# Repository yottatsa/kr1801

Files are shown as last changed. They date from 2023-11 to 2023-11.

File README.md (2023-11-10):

# KR1801 computer

KiCAD goodies to work with K1801VM1

[Documenation](https://yottatsa.github.io/kr1801/).

## К1801ВМ1 (K1801VM1)

KiCAD symbol and footprint, 3D model.

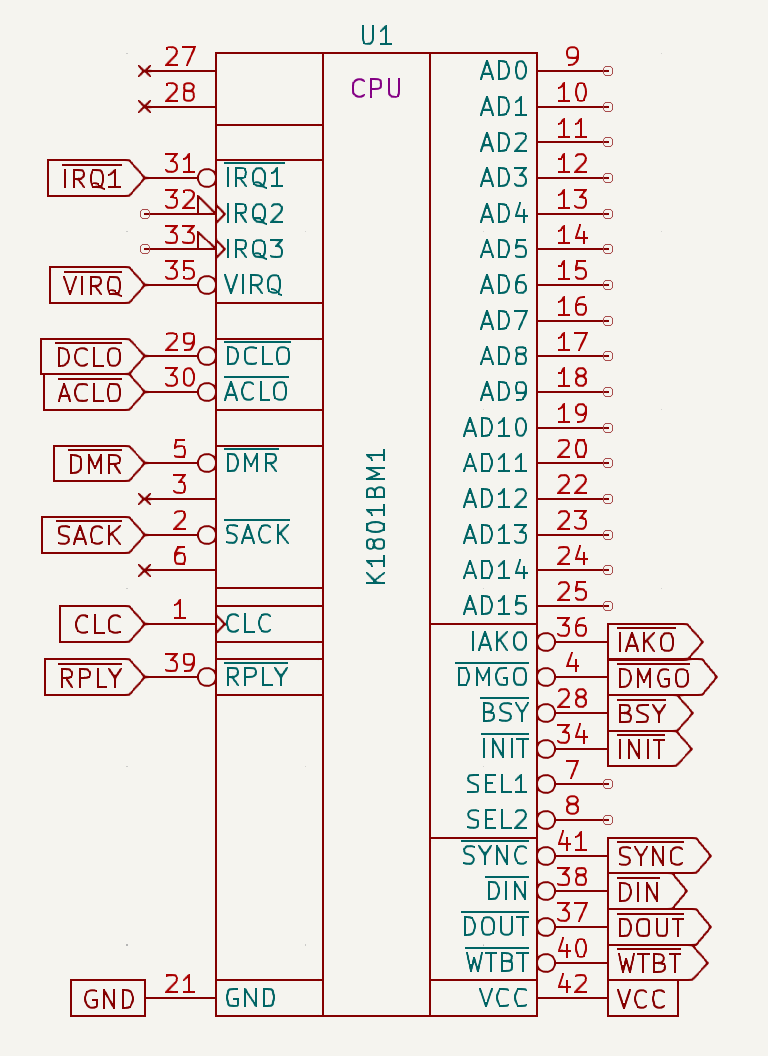
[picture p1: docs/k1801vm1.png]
Screenshot of a K1801VM1 KiCAD symbol


## Retrobrew EuroCard bus v6

KiCAD symbol with most of the pins in 16bit configuration (to be finished).

## KR1801VM1 ECB card

Minimal card that has clock and facilities to boot.

## Documentation sources

* [1801BM1/cpu11](https://github.com/1801BM1/cpu11/tree/6452c7d89c5c2e69dccbcec1f96eda947a3de05e/vm1/doc)
* [arktur04/1801VM1_docs](https://github.com/arktur04/1801VM1_docs)

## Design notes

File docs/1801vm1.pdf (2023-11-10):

# Однокристальный микропроцессор К1801ВМ1 Техническое описание

## Версия 1.2 (October 24, 2020)

Однокристальный микропроцессор К1801ВМ1 | Version: 1.2
Техническое описание © 1801BM1@gmail.com | Date: 24-Oct-2020

### 1. Введение

Данный документ описывает микросхему советского однокристального микропроцессора К1801ВМ1. В открытом доступе не имеется официального технического описания данного процессора, а различные источники не являются полными и непротиворечивыми, поэтому было принято решение составить техническое описание, основанное на имеющихся фрагментах официальных документов, проверенных на практике фактов и результатах реверс-инжиниринга собственно микросхемы К1801ВМ1.

По возможности ссылки на использованные материалы приведены в соответствующем разделе.

В тексте не делается различия между разными исполнениями корпуса - КМ1801ВМ1 (керамический), КР1801ВМ1 (пластиковый корпус) и прочими, вместо этого употребляется единое обозначение К1801ВМ1.

Изначально, когда выполнялся реверс-инжиниринг микросхемы К1801ВМ1А, предполагалось что микросхемы с другими буквенными индексами (К1801ВМ1Б, К1801ВМ1В, К1801ВМ1Г) являются результатом сортировки по частоте и работоспособности отдельных блоков после выполнения заводских тестов. Данное предположение оказалось только частично верным. Микросхема К1801ВМ1Г выпускалась по другим фотошаблонам слоя диффузии и содержит микропрограмму, отличную от микропрограммы микросхемы К1801ВМ1А. Функциональные отличия микросхемы К1801ВМ1Г заключаются в поддержке команды умножения, гарантировано работоспособном блоке таймера и поддержке прерывания от этого блока. Поскольку данные отличия незначительны, то возможно написание единой документации на все варианты К1801ВМ1, с акцентированным описанием дополнительных особенностей версии К1801ВМ1Г.

### 2. Назначение

Микросхема К1801ВМ1 является однокристальным 16-ти разрядным микропроцессором (далее по тексту процессор), предназначенным для обработки цифровой информации.

В составе ЭВМ процессор может использоваться для управления технологическими процессами, в контрольно-измерительной аппаратуре, в системах связи, для решения инженерно-технических и экономических задач.

### 3. Технические характеристики

Представление чисел | дополнительный код с фиксированной запятой
Система команд | безадресная, одноадресная, двухадресная
Виды адресации | регистровая, косвенно-регистровая, автоинкрементная, косвенно-автоинкрементная, автодекрементная, косвенно-автодекрементная, индексная, косвенно-индексная
Число регистров общего назначения | 8
Число уровней прерываний | 4
Системная магистраль | типа МПИ
Адресное пространство | 64 килобайта
Тактовая частота К1801ВМ1А К1801ВМ1Б К1801ВМ1В К1801ВМ1Г | минимальная 100 кГц для всех вариантов (ограничение частоты снизу связано с тем, что для построения некоторых защелок используется емкость затворов n-МОП транзисторов) до 4.7 МГц (ВМ1А) до 3.5 МГц (ВМ1Б) до 2.5 МГц (ВМ1В) до 4.7 МГц (ВМ1Г)
Максимальное быстродействие (регистровые операции) | до 500 тысяч операций в секунду
Напряжение питания | однополярное единое питание +5 В ±10%
Многопроцессорность | до 4-х процессоров на единой магистрали
Уровни входных логических сигналов низкого уровня высокого уровня | не более 0.6 В, при токе не утечки не более 50мкА не менее 2.4 В, при токе не утечки не более 50мкА
Уровни выходных логических сигналов низкого уровня высокого уровня | не более 0.5 В, при втекающем токе 3.2мА не менее 2.4 В, при вытекающем токе -0.2 мА
Емкость нагрузки | до 100 пФ
Технология изготовления | n-МОП, типовая ширина затвора транзистора ~3 мкм, один слой металла и один слой поликремния
Размер кристалла | 5х5 мм
Конструкция | Металлокерамический корпус типа 429.42 или пластиковый 2204.42-3
Количество транзисторов | ~16650 штук
Потребляемая мощность | до 1.2 Вт

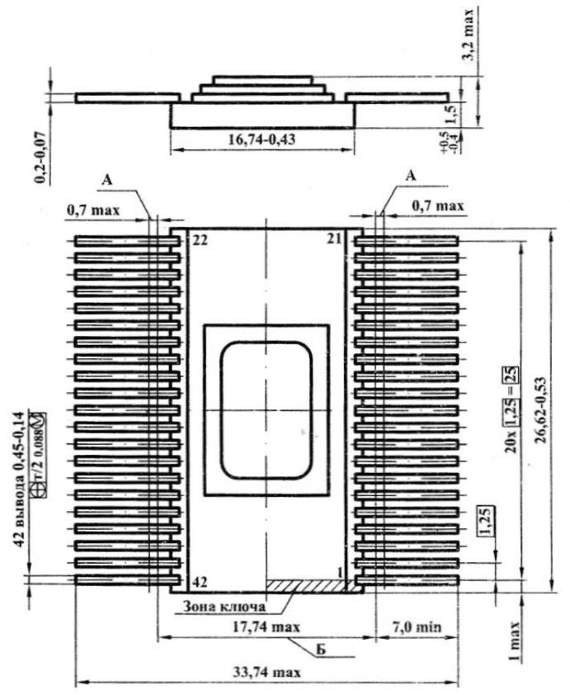
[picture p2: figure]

Чертеж планарного металлокерамического корпуса типа 429.42-5

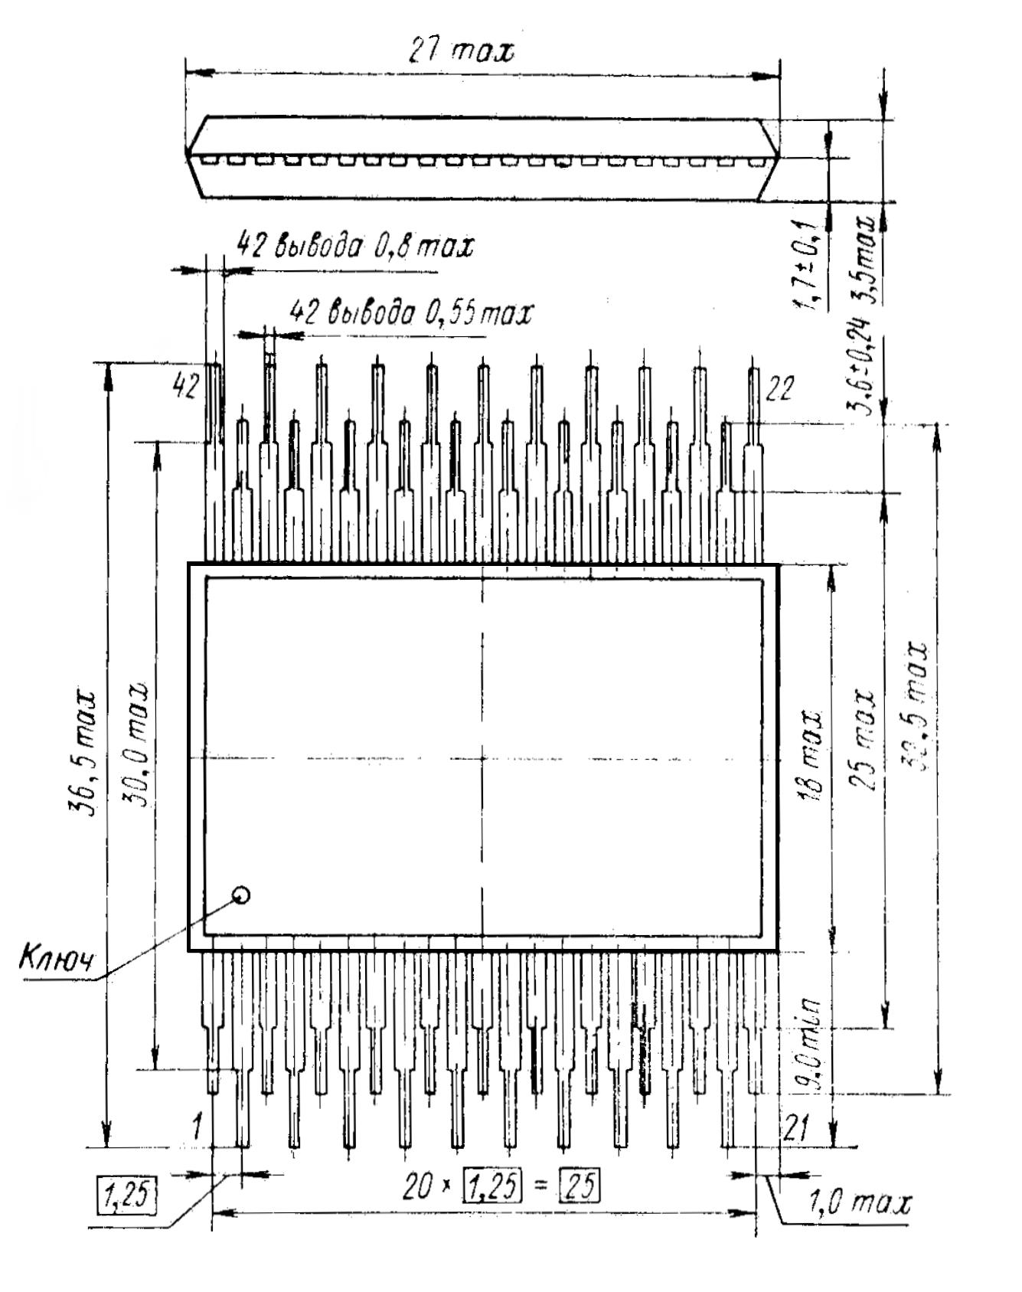
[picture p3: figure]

Чертеж планарного пластикового корпуса 2204.42-3

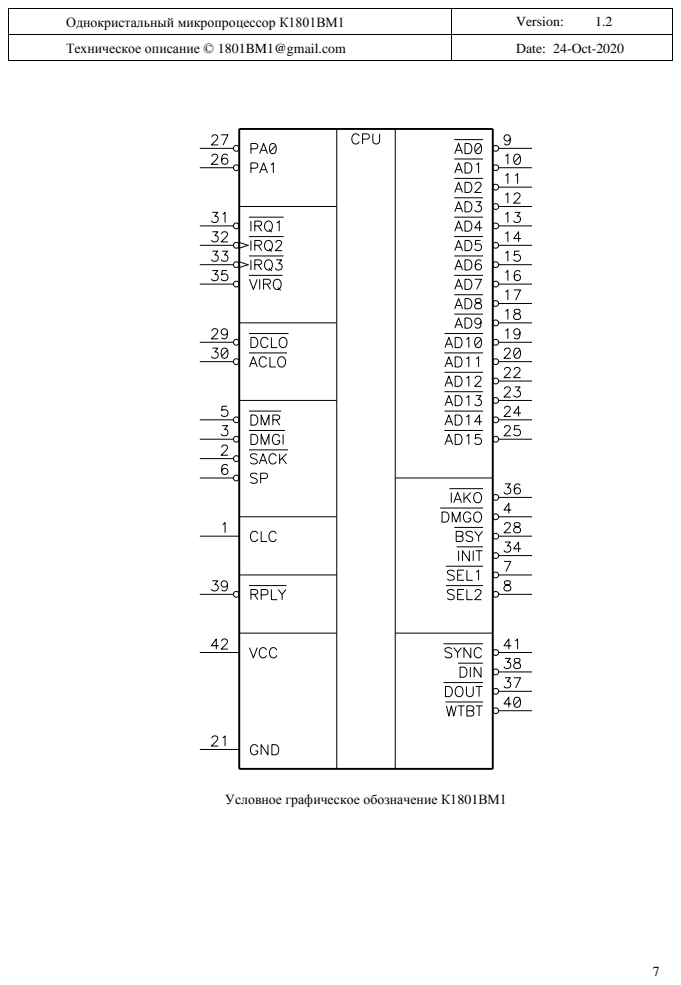
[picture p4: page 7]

Условное графическое обозначение К1801ВМ1

### 4. Назначение выводов

1 | CLC | вход | Основной тактовый сигнал частотой не менее 100 кГц, ограничение частоты снизу связано с широким применением динамической логики в схеме процессора. Под динамической логикой понимается использование емкостных свойств затворов n-МОП транзисторов, вследствие чего транзисторы могут некоторое время сохранять свое состояние при затворе, отключенном от источника сигнала
2 | nSACK | вход выход-ОК | Подтверждение захвата магистрали внешним агентом Ведущий процессор с аппаратным номером 0 никогда не активизирует данный выход (типа открытый коллектор). Ведомые процессоры с номерами 1-3 выставляют на данном выходе низкий уровень в процессе обмена по магистрали. Как вход используется всеми процессорами для общего контроля занятости магистрали
3 | nDMGI | вход | Разрешение от внешнего арбитража на доступ к магистрали, если процессор в данный момент занят выполнением внутренних операций и ему не требуется доступ к магистрали, то обеспечивается дальнейшее прохождение разрешающего сигнала на выход nDMGO
4 | nDMGO | выход | Разрешение на доступ к магистрали другим, менее приоритетным модулям. Активный низкий уровень появляется в моменты, когда на входе nDMGI низкий уровень и внутреннему процессорному блоку не требуется доступ к магистрали
5 | nDMR | вход выход-ОК | Для ведущего процессора с аппаратным номером 0 этот вывод является входом запроса на доступ к магистрали от ведомых процессоров с номерами 1-3 и других внешних модулей системы, ведущий процессор никогда не использует данный вывод как выход. Ведомые процессоры с номерами 1-3 используют данный вывод как выход запроса на доступ к магистрали
6 | nSP | вход | Вход периферийного таймера, может использоваться как внешняя тактовая частота, не превышающая одной восьмой тактовой частоты процессора, или как вход защелкивания текущего значения счетчика таймера в отдельном регистре. Все действия в таймере (счет и защелкивание) происходят по ниспадающему фронту сигнала на данном входе с задержкой от 1 до 8 тактов процессорной частоты CLC
7 | nSEL1 | выход-ОК | Сигнал подтверждения обращения по адресу база внутреннего периферийного блока + 168. Формируется всегда, независимо от того какой агент, внутренний или внешний обращается к данному адресу.
8 | nSEL2 | выход-ОК | Сигнал подтверждения обращения по адресу база внутреннего периферийного блока + 148. Формируется всегда, независимо от того какой агент, внутренний или внешний обращается к данному адресу.

9-20,
22-25

nAD0-
nAD15

входы
выходы-3

Линии 16-ти разрядной мультиплексированной шины адреса и данных. Сигналы передаются по данным линиям в инвертированном виде. Передача значения адреса и данных осуществляется методом разделения во времени.

Если системной магистралью МПИ владеет внутренний процессорный блок, то выводы nAD работают как выходы:

- в фазе передачи адреса
- в фазе записи данных во всем диапазоне адресов
- в фазе чтения данных из диапазона адресов внутреннего периферийного блока , за исключением двух старших адресов nSEL1 и nSEL2.
Если системной магистралью МПИ владеет внешний по отношению к микросхеме агент , то выводы nAD работают как выходы:
- в фазе чтения данных по адресам внутреннего периферийного блока

В остальное время выходы находятся в высокоимпедансном состоянии. Входы в целях мониторинга адреса транзакции и данных записи работают постоянно.

26, 27 | nPA1, nPA0 | входы | Аппаратный номер процессора в многопроцессорной системе, сигналы на данных входах являются инвертированными. nPA1=1, nPA0=1 - процессор номер 0, высший приоритет nPA1=1, nPA0=0 - процессор номер 1 nPA1=0, nPA0=1 - процессор номер 2 nPA1=0, nPA0=0 - процессор номер 3, низший приоритет Если процессор единственный в системе (однопроцессорный вариант), то на данные входы должен быть подан высокий уровень. От аппаратного номера процессора зависит базовый адрес блока регистров внутреннего периферийного блока.
28 | nBSY | выход-ОК | Низкий уровень на данной выходе сигнализирует о выполнении транзакции на шине МПИ
29 | nDCLO | вход | Авария источника питания постоянного напряжения. Низкий уровень на данном входе выставляется внешней схемой при выходе питающего напряжения системы (обычно +5V и +12V) за допустимые рабочие диапазоны, при этом происходит безусловный аппаратный сброс процессора.
30 | nACLO | вход | Авария сетевого источника питания. Низкий уровень на данном входе выставляется внешней схемой при выходе сетевого питающего напряжения за пределы рабочего диапазона, при этом внутренние постоянные питающие напряжения все еще могут обеспечиваться. Ниспадающий фронт вызывает прерывание по вектору 0248, для устойчивой работы процессора сигнал следует синхронизировать по нарастающему фронту с тактовой частоты CLC. По нарастающему фронту сигнала происходит старт микропрограммного автомата, если он был сброшен ранее активным сигналом nDCLO

31 | nIRQ1 | вход | Первый запрос на радиальное прерывание, низкий уровень вызывает прерывание по вектору 1600028. Для устойчивой работы процессора сигнал следует синхронизировать по нарастающему фронту с тактовой частоты CLC
32 | nIRQ2 | вход | Второй запрос на радиальное прерывание, ниспадающий фронт вызывает прерывание по вектору 1008, для устойчивой работы процессора сигнал следует синхронизировать по нарастающему фронту с тактовой частоты CLC
33 | nIRQ3 | вход | Третий запрос на радиальное прерывание, ниспадающий фронт вызывает прерывание по вектору 2708, для устойчивой работы процессора сигнал следует синхронизировать по нарастающему фронту с тактовой частоты CLC
34 | nINIT | вход выход-ОК | Вход сброса периферийных устройств. Низкий уровень на данном входе переводит периферийный таймер в исходное состояние и временно снимается активный запрос nDMR. Также приводятся в исходное состояние детекторы ниспадающего фронта на входах nIRQ2 и nIRQ3. На выходе (открытый коллектор) формируется активный сигнал низкого уровня при выполнении инструкции RESET и/или аппаратном сбросе процессора
35 | nVIRQ | вход | Запрос на векторное прерывание, низкий уровень вызывает цикл подтверждения прерывания на шине МПИ и переход по прочитанному из внешнего устройства вектору. Для устойчивой работы процессора сигнал следует синхронизировать по нарастающему фронту тактовой частоты CLC. Следует отметить, что только ведущий процессор с аппаратным номером 0 может принимать и обрабатывать прерывания по данному входу, в ведомых процессор с аппаратными номерами 1-3 этот вход заблокирован.
36 | nIAKO | выход-3 | Выход предоставления прерывания, низкий уровень на данном выходе появляется в циклах чтения вектора прерывания из внешнего устройства. Когда доступ к шине МПИ процессору не предоставлен выход находится в высокоимпедансном состоянии
37 | nDOUT | вход выход-3 | Вывод данных, вход используется внутренним периферийным блоком для выполнения транзакций записи. Выходом управляет процессорный блок в случае предоставления ему доступа к шине МПИ. Когда доступ к шине процессору не предоставлен выход находится в высокоимпедансном состоянии
38 | nDIN | вход выход-3 | Ввод данных, вход используется внутренним периферийным блоком для выполнения транзакций чтения. Выходом управляет процессорный блок в случае предоставления ему доступа к шине МПИ, когда доступ к шине процессору не предоставлен выход находится в высокоимпедансном состоянии
39 | nRPLY | вход выход-ОК | Подтверждение обмена данными, вход используется процессорным блоком при выполнении транзакций на шине МПИ. На выходе генерируется активный низкий уровень периферийным блоком в случае любого обращения в его диапазон адресов, включая регистры nSEL1 и nSEL2. Из-за выявленных ошибок в схеме процессора

| | | сигнал на данном входе следует синхронизировать с тактовым сигналом CLC (с любым из фронтов) для обеспечения устойчивой работы
40 | nWTBT | выход-3 | Запись/байт, в фазе трансляции адреса данный выход индицирует низким уровнем что в данной транзакции будет осуществляться вывод данных. Для циклов чтение и чтение-модификация-запись на данном выходе присутствует высокий уровень. В фазе обмена данными низкий уровень свидетельствует о записи одного из байтов, а не целого слова. Какой именно байт записывается определяется состоянием младшей адресной линии в фазе передачи адреса. Когда доступ к шине процессору не предоставлен выход находится в высокоимпедансном состоянии
41 | nSYNC | вход выход-3 | Вход используется периферийным блоком для мониторинга адреса транзакции. Выходом управляет процессорный блок при выполнении транзакций на шине МПИ. При этом выход имеет особенность -высокий уровень генерируется ровно на один такт частоты CLC, после чего выход переводится в высокоимпедансное состояние, поэтому для нормальной работы линия должна быть подтянута резистором к напряжению питания.
21 | GND | земля | опорный уровень 0В, питание
42 | VCC | питание | +5В с допуском ±10%, ток потребления до 240мА

Микросхема К1801ВМ1 содержит внутри два основных блока - собственно блок процессора и периферийный блок. Оба блока подключены к единой магистрали типа МПИ, которая также выходит на внешние выводы. Блок процессора может работать только как ведущий агент МПИ, периферийный блок может работать только как ведомый агент МПИ. Доступ процессорного блока к управлению МПИ контролируется модулем арбитража. Периферийный блок представляет собой набор различных специальных регистров, для периферийного блока выделен адресный диапазон из 8 16-ти разрядных слов, базовый адрес которого определяется аппаратным номером процессора. Внешние выводы МПИ микросхемы К1801ВМ1 выполняют совмещенные функции для процессорного и периферийного блоков. Доступ к периферийному блоку может осуществляться как со стороны внутреннего процессорного блока, так и со стороны внешнего по отношению к микросхеме процессора агента шины МПИ. Таким образом, можно выделить основные четыре режима работы внешних выводов МПИ микросхемы К1801ВМ1:

- доступ внутреннего процессорного блока к внешним адресам системы (которые, в том числе, могут быть адресами периферийного блока другой микросхемы К1801ВМ1 в многопроцессорной системе)
- доступ внутреннего процессорного блока к адресам внутреннего периферийного блока
- доступ внешнего агента к внешним адресам системы
- доступ внешнего агента к адресам внутреннего периферийного блока данного процессора

Особый случай представляют два старших адреса периферийного блока, эти регистры могут реализовываться на внешних схемах, но при этом управление обменом по МПИ осуществляется процессором, внешние схемы только представляют или получают данные, сигнал nRPLY формируется выходом К1801ВМ1 всегда, при обращении к любому адресу из диапазона периферийного блока.

Процессор К1801ВМ1 может работать в составе многопроцессорной системы с разделением общей магистрали МПИ. Система на основе К1801ВМ1 может содержать до 4-х процессоров. Процессорам присваивается аппаратный номер от 0 до 3, в зависимости от уровней, поданных на входы nPA0-nPA1. Процессор с аппаратным номером 0 называется ведущим и имеет высший приоритет при доступе к разделяемой шине МПИ, начиная цепочку арбитража по выводам nDMGI/nDMGO. Остальные процессоры с номерами 1-3 называются ведомыми, приоритет доступа к разделяемой шине определяется местом включения процессора в цепочку арбитража доступа к шине

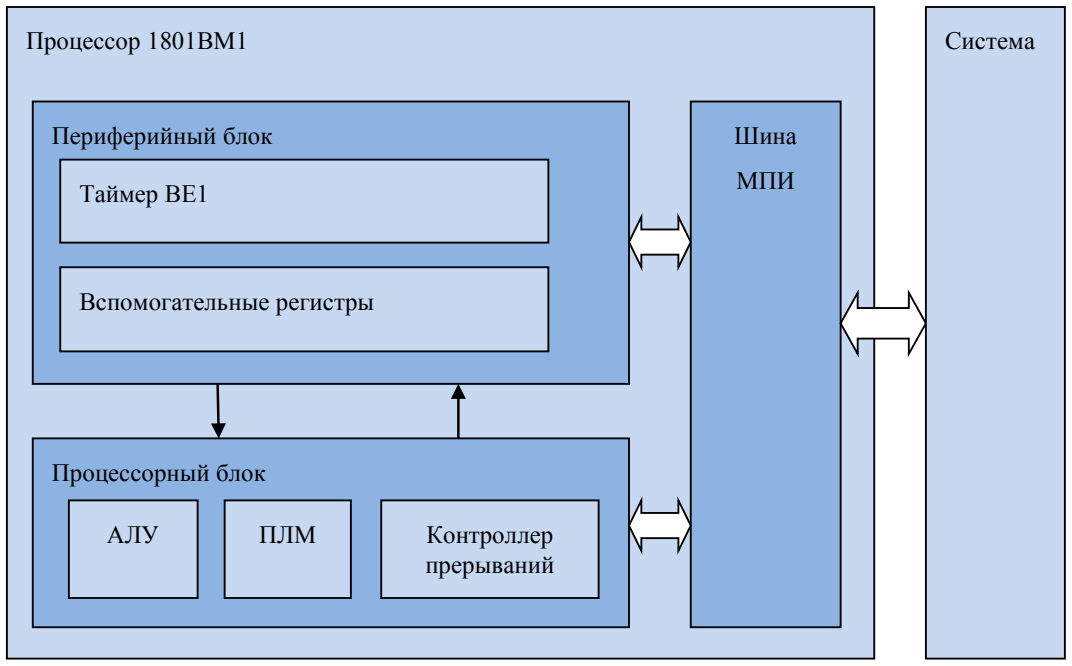
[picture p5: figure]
Процессор 1801ВМ1; Периферийный блок; Процессорный блок; Шина; МПИ Таймер ВЕ1; Вспомогательные регистры; АЛУ; ПЛМ; Контроллер; прерываний; Система

### 5. Шина МПИ

Микропроцессор К1801ВМ1 для обмена с внешними устройствами использует системную шину типа МПИ (Магистральный Параллельный Интерфейс). Обмен информацией между двумя устройствами по шине МПИ осуществляется по принципу ведомый-ведущий. Управление обменом осуществляет ведущее устройство, а ведомое устройство производит подтверждение приема или передачи слова данных. Некоторые устройства могут в разные моменты времени выполнять роль как ведущего, так и ведомого. В каждый момент времени на шине МПИ может быть только одно ведущее устройство, которое физически осуществляет управление линиями магистрали. Доступ устройства к роли ведущего шины разрешается средствами приоритетного арбитража. Подробно с регламентом работы МПИ можно ознакомиться в стандарте "ГОСТ 26765.51-86 Интерфейс магистральный параллельный МПИ системы электронных модулей. Общие требования к совокупности правил обмена информацией" [6]. Данная же документация делает акцент именно на особенностях работы микропроцессора, для понимания принципов работы внешних устройств следует обратиться к упомянутому ГОСТ.

Микропроцессор К1801ВМ1 может выполнять роль ведущего устройства шины - в этом случае процессорный блок выполняет транзакции "Ввод" (чтение данных из внешнего устройства), "Вывод" (запись данных во внешнее устройство), "Ввод-Вывод" (чтение-модификация-запись), "Подтверждение прерывания" (чтение вектора прерывания). Так же микросхема К1801ВМ1 может выполнять роль ведомого устройства - в этом случае осуществляется доступ внешним агентом к периферийному блоку микросхемы, а также выполнять обе роли ведущего и ведомого устройств одновременно - при обращении процессорного блока к собственному (то есть, находящемуся в той же микросхеме) периферийному блоку. Блочные транзакции шины МПИ микропроцессор К1801ВМ1 не использует.

### 5.1 Транзакция "Чтение"

Ниже приведена диаграмма выполнения микропроцессором цикла чтения данных по шине МПИ в качестве ведущего устройства. Пунктирными линиями показано состояние высокого импеданса. Обычно в системе на линиях магистрали имеются подтягивающие резисторы, поэтому можно полагать что в эти моменты времени на линиях присутствует напряжение высокого уровня, все управляющие сигналы при этом принимают неактивное значение, на шине адрес/данных устанавливается логическое нулевое значения, поскольку шина инвертирована (напряжение низкого уровня соответствует логическому "1", напряжение высокого уровня соответствует логическому "0").

Также указана привязка установки и снятия управляющих выходов к фронтам тактового сигнала, при этом не учитывается внутренняя задержка буферных цепей, которая может достигать десятков наносекунд и, при высоком значении тактовой частоты, может быть сравнимой с длительностью такта.

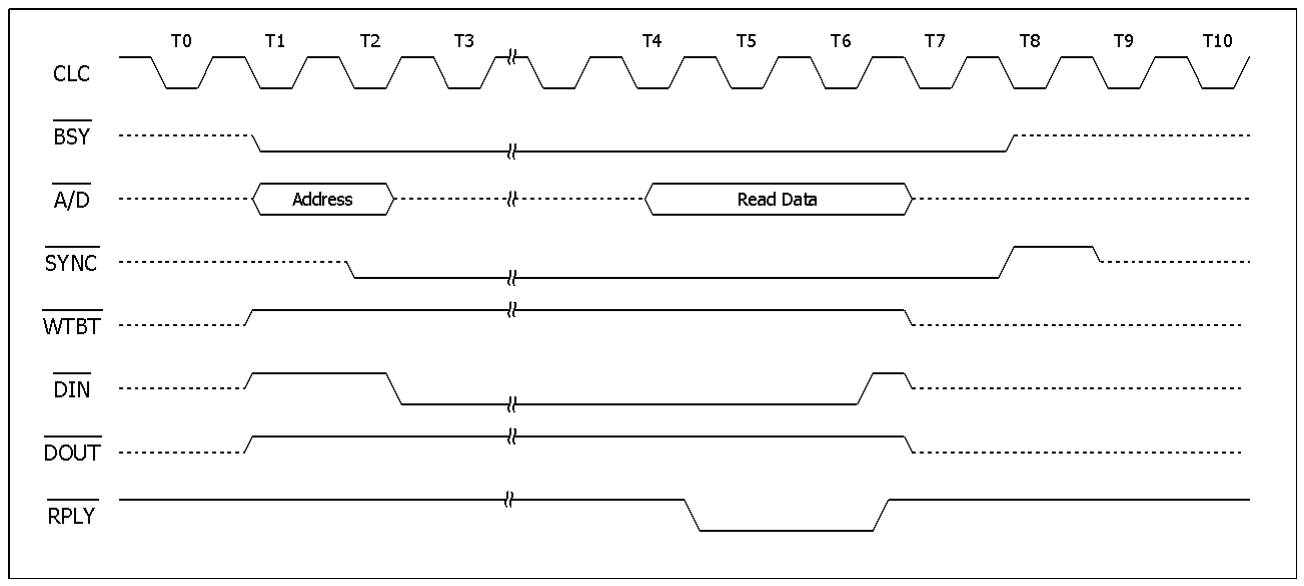
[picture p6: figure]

В такте Т0 на магистрали МПИ нет ведущего устройства, обмен не выполняется, полагаем это состояние исходным. По срезу Т1 микропроцессор осуществляет захват магистрали (процесс арбитража рассмотрен подробно в соответствующем разделе), при этом разрешается управление выходами nWTBT, nDIN, nDOUT, nIAKO, A/D. Сигнал nBSY принимает активный низкий уровень, на шине адреса/данных устанавливается адрес читаемых данных. Выход сигнала nSYNC остается запрещенным — это особенность К1801ВМ1, для корректной работы шины в этом случае требуется внешний подтягивающий резистор. На выходе nWTBT установлен высокий уровень, что означает выполнение операции чтения. По срезу Т2 на выходе nSYNC формируется активный низкий уровень. По фронту Т2 выставленный адрес снимается с шины и выводы nAD переводятся в высокоимпедансное состояние, также выставляется активный низкий уровень на линии nDIN, далее микропроцессор переходит в состояние ожидания данных и сигнала подтверждения nRPLY от ведомого устройства. При этом запускается специальный таймер монитора шины, который осуществляет счет с частотой CLC/8. Если сигнал подтверждения nRPLY не будет получен в течение 56...64 тактов CLC, то цикл обмена прерывается и возникает программное исключение по вектору 0000048 (или 1600028 - зависит от состояния битов PSW10 и PSW11). Разброс в величине таймаута связан с тем, что фаза предделителя частоты CLC/8 при запуске таймера не обнуляется - предделитель считает непрерывно.

На диаграмме в такте Т4 внешнее устройство выставляет данные, которые подлежат считыванию микропроцессором, и затем, по прошествии некоторого интервала формирует активный низкий уровень сигнала подтверждения nRPLY. В общем же случае, согласно ГОСТ 26765.51-86, актуальные данные должны быть выставлены ведомым устройством не позднее чем 200 нс после среза активации сигнала nRPLY. На диаграмме момент выставления nRPLY, который определяется внешним устройством, намерено показан после фронта T4. Микропроцессор фиксирует сигнал на своем входе nRPLY по нарастающему фронту тактового сигнала, при обнаружении активного низкого nRPLY два фронта тактового сигнала подряд (на приведенной диаграмме это T5 и T6, два цикла нужны так как данные от ведомого устройства могут запаздывать на интервал до 200 нс относительно активации nRPLY), цикл обмена полагается законченным, по фронту T6 фиксируются читаемые данные на входах nAD и передаются внутренним схемам процессора, снимается активный сигнал nDIN и останавливается таймер монитора шины, затем происходит переход в ожидание снятия активного сигнала nRPLY. При этом детектирование неактивного высокого уровня nRPLY осуществляется по последовательным фронту и срезу тактового сигнала - сигнал на входе nRPLY должен быть неактивен сначала при нарастающем фронте CLK, а потом на срезе CLK следующего такта - таково условие срабатывания детектора. При обнаружении неактивного высокого уровня nRPLY запрещаются выходы управляющих сигналов nDIN, nDOUT, nWTBT. Далее, еще через один такт происходит снятие сигнала nBSY и выставление высокого уровня сигнала nSYNC. На диаграмме фронт сигнала nRPLY обнаруживается по срезу Т7, а снятие сигналов nSYNC и nBSY происходит по срезу Т8. Высокий неактивный уровень nSYNC удерживается в течение одного такта и по срезу Т9 выход переходит в высокоимпедансное состояние, микропроцессор перестает выполнять роль ведущего устройства, магистраль полагается незанятой. Следует отметить, что таймер монитора шины в состоянии ожидания деактивации nRPLY не работает, поэтому имеется теоретическая возможность зависания системы.

Микропроцессор К1801ВМ1 чтение данных всегда выполняет 16-битными словами. Если требуется прочитать только один из байтов, то ненужные разряды игнорируются. Также микропроцессор выставляет адрес "как есть" (например чтение по @R0 выставляет на шину адреса непосредственно значение из регистра R0, @#000001 - на шину будет выставлено значение 1 и так далее), и чтение слов по нечетному адресу может приводить к некорректно прочитанным данным, поскольку внешняя память и устройства обычно не поддерживают такой режим - в этом случае для корректного чтения внешним схемам необходимо прочитать из памяти два последовательных слова и собрать из них ожидаемую процессором комбинацию байтов. При чтении байта по четному адресу процессор ожидает данные на линиях nAD0-nAD7, при чтении байта по нечетному адресу данные ожидаются на линиях nAD8-nAD15.

Ниже в справочных целях приведена диаграмма выполнения транзакции "Чтение" из ГОСТ 26765.51-86 с указанием регламентируемых временных параметров.

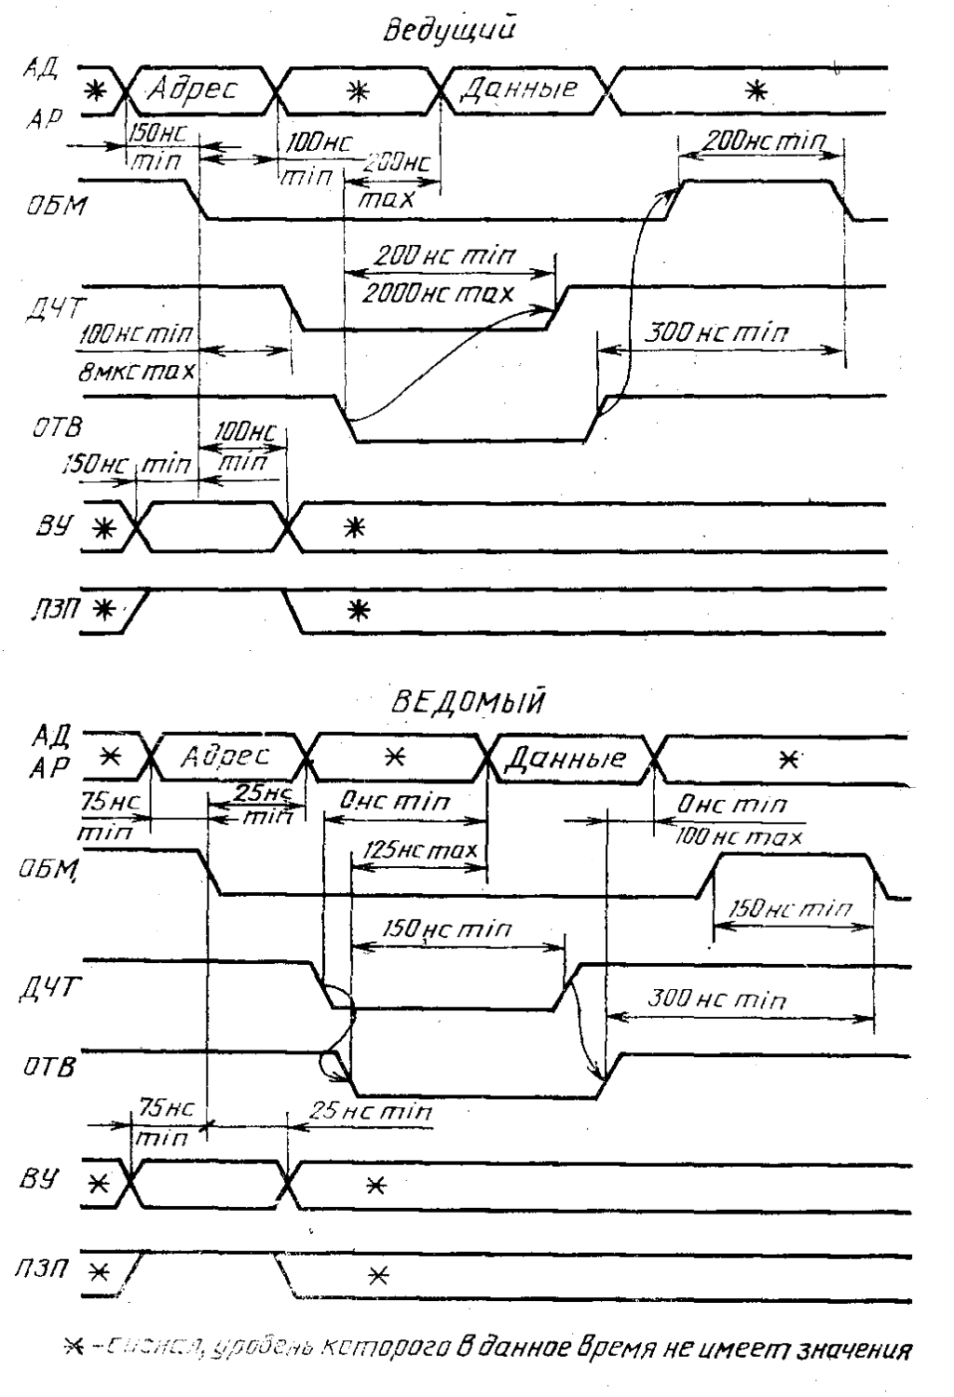
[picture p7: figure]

### 5.2 Транзакция "Запись"

Ниже приведена диаграмма выполнения микропроцессором цикла записи данных по шине МПИ в качестве ведущего устройства.

Начало транзакции аналогично началу транзакции "Чтение". В такте Т0 на магистраль МПИ находится в исходном незанятом состоянии, по срезу Т1 микропроцессор осуществляет захват магистрали, при этом разрешается управление выходами nWTBT, nDIN, nDOUT, nIAKO, A/D. Сигнал nBSY принимает активный низкий уровень, на шине адреса/данных устанавливается адрес записываемых данных. Выход сигнала nSYNC остается запрещенным (особенность К1801ВМ1). На выходе nWTBT установлен низкий уровень, что означает выполнение операции записи. По срезу Т2 на выходе nSYNC формируется активный низкий уровень. По фронту Т2 выставленный адрес снимается с шины, выходы nAD остаются разрешенными и на них транслируется содержимое внутреннего регистра данных микропроцессора. В данный момент там необязательно могут находиться актуальные записываемые в текущей транзакции данные - они могут быть еще не подготовлены внутренними схемами процессора. Время подготовки зависит от того какая программная инструкция в данный момент обрабатывается микропрограммой и может составлять от нуля до нескольких тактов. При готовности данных во внутреннем регистре они начинают транслироваться на внешние выходы по фронту тактового сигнала. Для краткости диаграммы полагаем, что данные выданы внутренними схемами в такте T3, практически же подготовка данных может занимать от нуля до нескольких тактов. По срезу следующего сигнала T4 выставляется активный низкий уровень на линии nDOUT и значение признака байтовой операции nWTBT. Если происходить запись только одного из байтов, то данный признак принимает значение активного низкого уровня. Запись, какого именно байта следует выполнить, определяется значением младшего бита адреса операции. Если происходит запись слова, то признак nWTBT принимает неактивное значение высокого уровня, выполнение операции записи слова по нечетному адресу приводит к некорректной записи данных. Далее микропроцессор переходит в состояние ожидания данных и сигнала подтверждения nRPLY от ведомого устройства. При этом запускается специальный таймер монитора шины, который осуществляет счет с частотой CLC/8. Если сигнал подтверждения nRPLY не будет получен в течение 56...64 тактов CLC, то цикл записи прерывается и возникает программное исключение по вектору 0000048 (или 1600028).

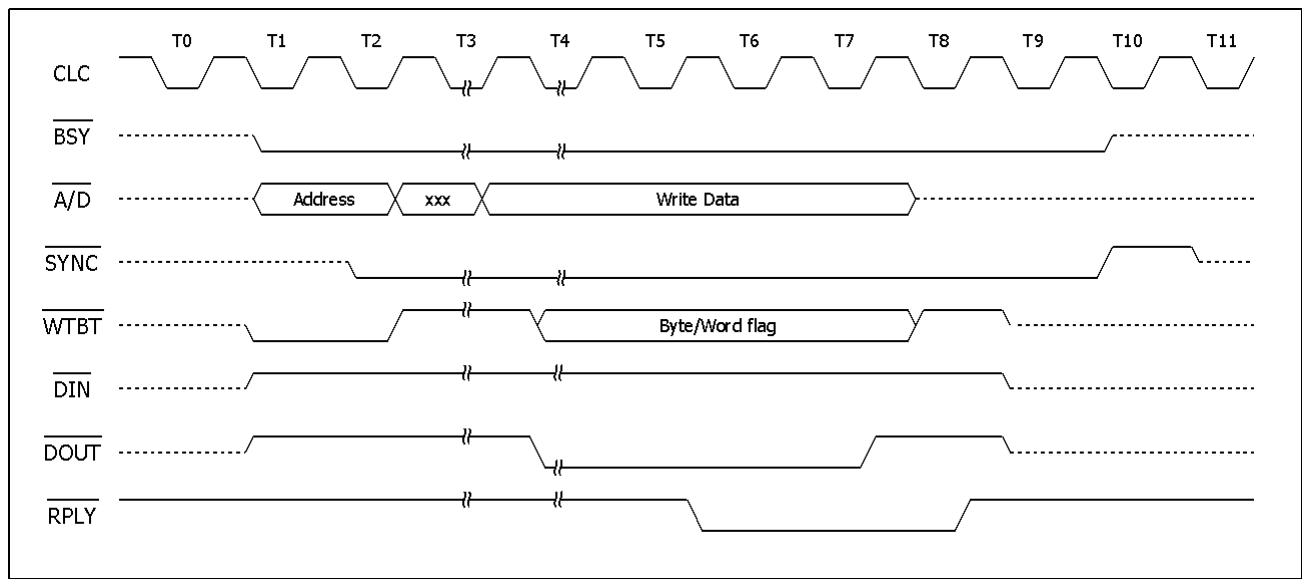
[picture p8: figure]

В такте Т5 внешнее устройство выполняет свою внутреннюю фиксацию записываемых данных с шины и затем, по прошествии некоторого интервала формирует активный низкий уровень сигнала подтверждения nRPLY. На диаграмме момент выставления nRPLY, который определяется внешним устройством, намерено показан после фронта T5. Микропроцессор фиксирует сигнал на своем входе nRPLY по фронту тактового сигнала, при обнаружении активного низкого nRPLY два фронта тактового сигнала подряд (на приведенной диаграмме это T6 и T7), цикл обмена полагается законченным. По фронту T7 деактивируется сигнал nDOUT и останавливается таймер монитора шины, по срезу T8 выходы шины данных A/D запрещаются, шина переходит в высокоимпедансное состояние. Завершение транзакции аналогично завершению транзакции "Чтение" - происходит переход в ожидание снятия активного сигнала nRPLY, при обнаружении деактивируются nSYNC и nBSY, магистраль переходит в неактивное состояние.

Ниже в справочных целях приведена диаграмма выполнения транзакции "Запись" из ГОСТ 26765.51-86 с указанием регламентируемых временных параметров

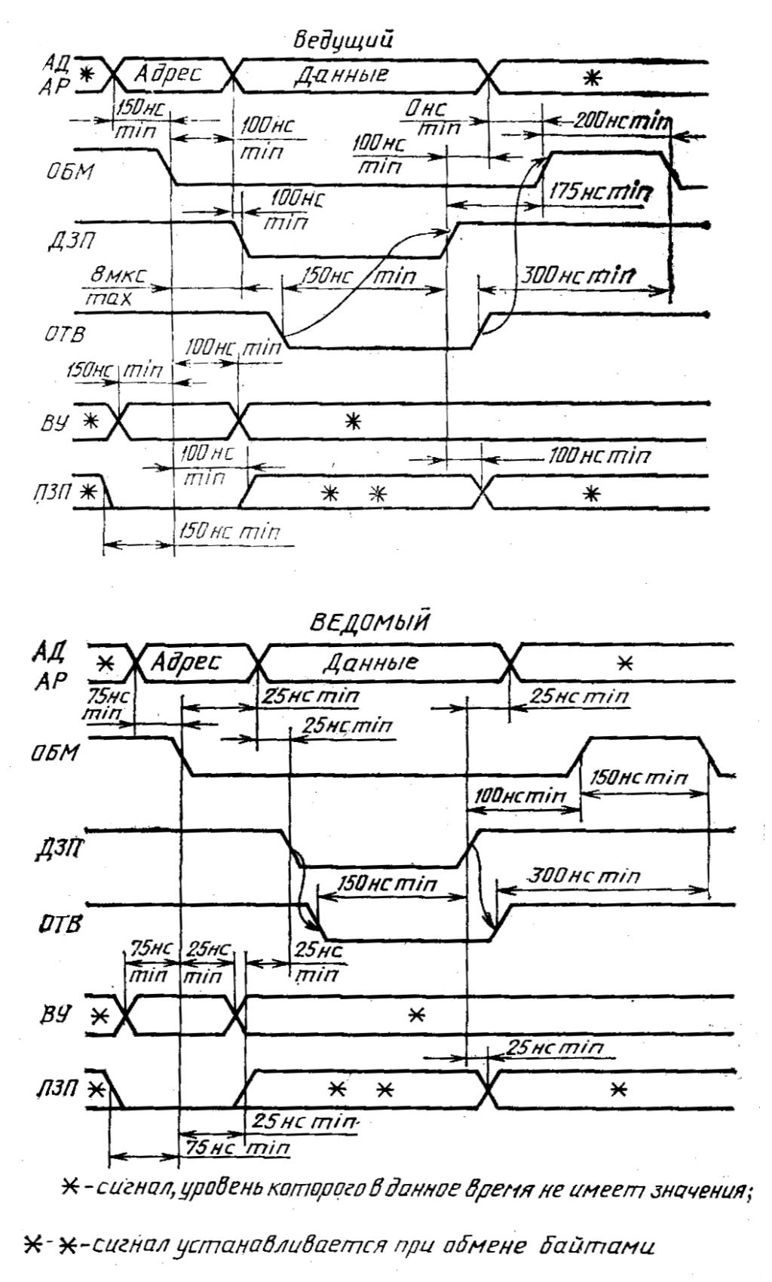
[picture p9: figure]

### 5.3 Транзакция "Чтение-Модификация-Запись"

Транзакция | "Чтение-Модификация-Запись" | имеет | принципиальное | значение | для
многопроцессорных систем, так как позволяет выполнять изменения переменных в памяти атомарно - за одну неразделяемую на части операцию. В этом ее принципиальное отличие от пары, состоящей из отдельной транзакции "Чтение" и последующей транзакцией "Запись" по тому же самому адресу. Ниже приведена диаграмма выполнения микропроцессором цикла чтение-модификация-запись по шине МПИ в качестве ведущего устройства.

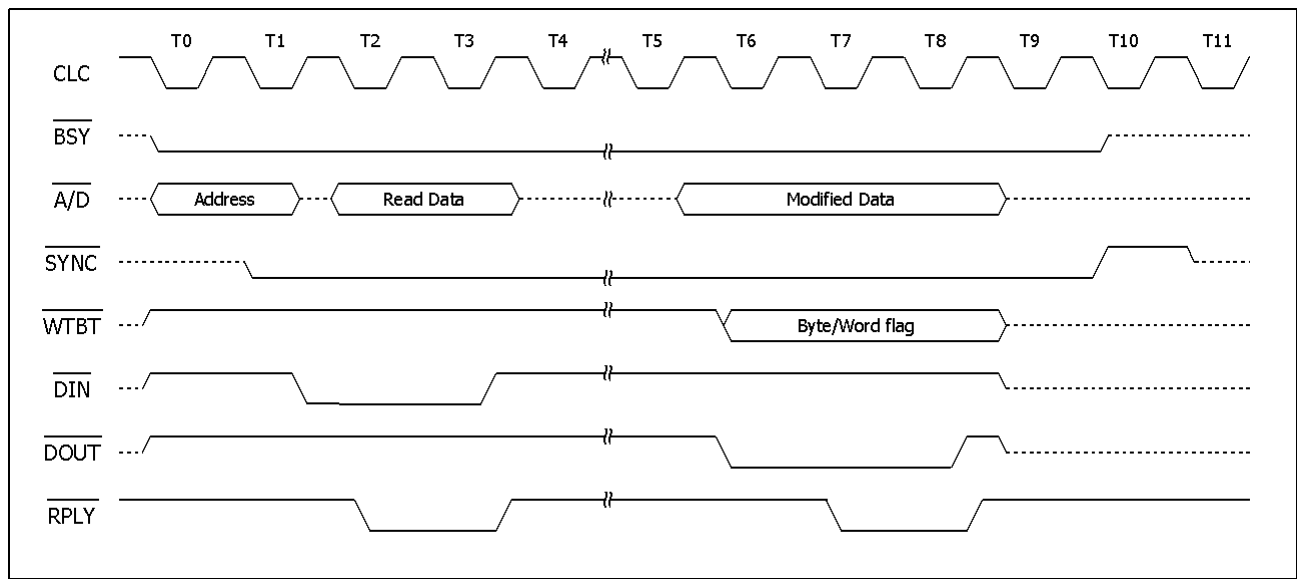
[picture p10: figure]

Начало транзакции модификации данных полностью аналогично транзакции "Чтение". На диаграмме для большей компактности удален начальный такт с неактивной магистралью МПИ. В момент фиксации данных по фронту Т3 прочитанные данные передаются внутренним схемам микропроцессора, которые немедленно начинают над этими данными требуемую арифметическую или логическую операцию, а интерфейсный блок переходит в состояние ожидания деактивации сигнала nRPLY, при этом сигналы nSYNC и nBSY остаются активными. Эти действия выполняются блоками параллельно и независимо. Процессорному блоку может потребоваться несколько тактов для выполнения операции над данными, после ее завершения данные записываются в специальный внутренний регистр данных. После того как интерфейсный блок по срезу тактового сигнала обнаружит неактивный nRPLY и в регистре данных уже будут готовые модифицированные данные по фронту тактового сигнала (T5 на диаграмме) будут разрешены выходы шины адреса/данных, и по срезу следующего тактового сигнала Т6 сформируется активный низкий уровень на выходе nDOUT и будет выставлен признак байтовой или словной операции. Завершение транзакции полностью аналогично завершению транзакции "Запись". Следует отметить, что таймер монитора шины перезапускается отдельно для каждой из фаз транзакции и не работает в паузе между ними, когда ожидается готовность модифицированных данных от АЛУ и деактивация nRPLY.

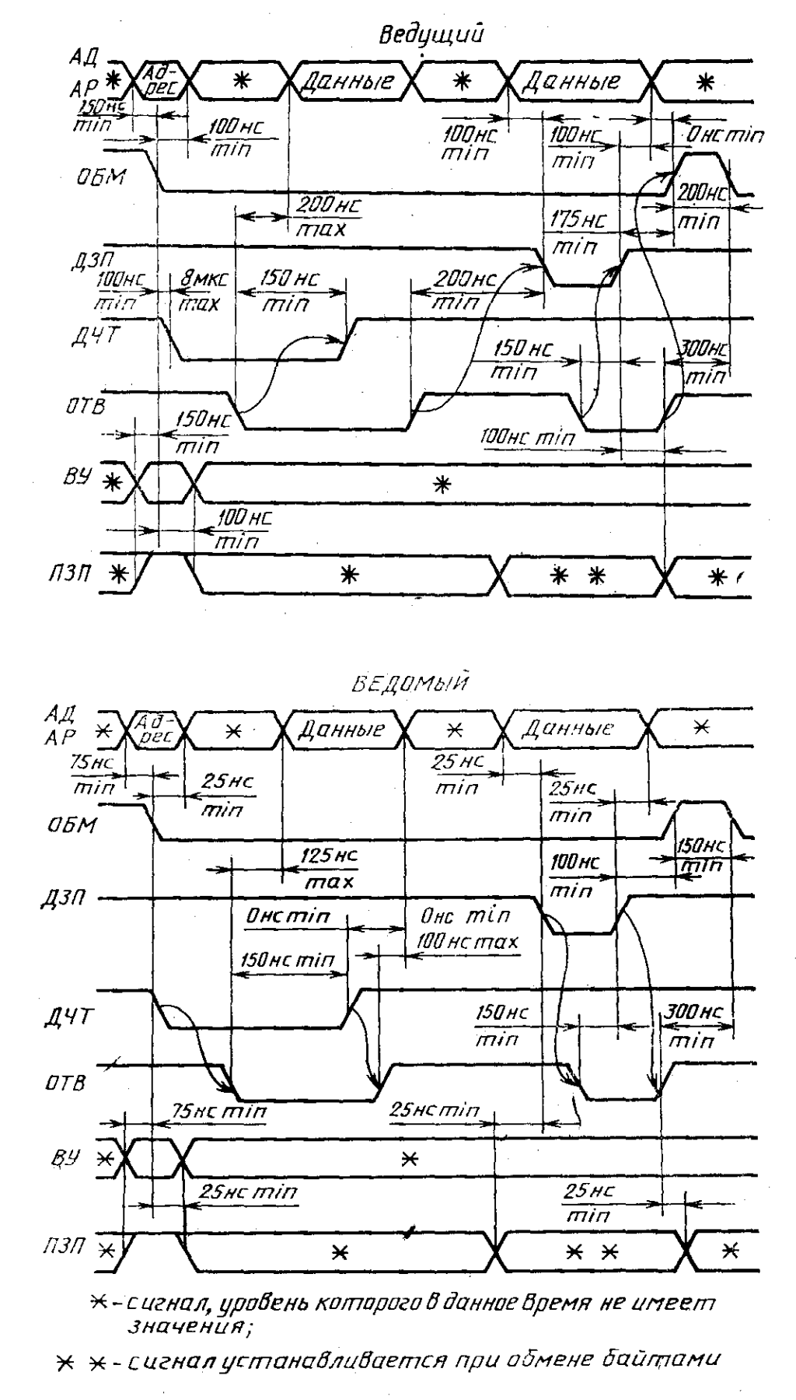
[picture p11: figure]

### 5.4 Транзакция "Подтверждение прерывания"

Ниже приведена диаграмма выполнения микропроцессором цикла чтения адреса вектора прерывания от внешнего устройства. Этот цикл выполняется процессором в рамках алгоритма обработки векторного прерывания после сохранения текущих PSW и PC в стеке. Пунктирными линиями показано состояние высокого импеданса.

Также указана привязка установки и снятия управляющих выходов к фронтам тактового сигнала, при этом не учитывается внутренняя задержка, которая может достигать десятков наносекунд и, при высоком значении тактовой частоты, может быть сравнимой с длительностью такта.

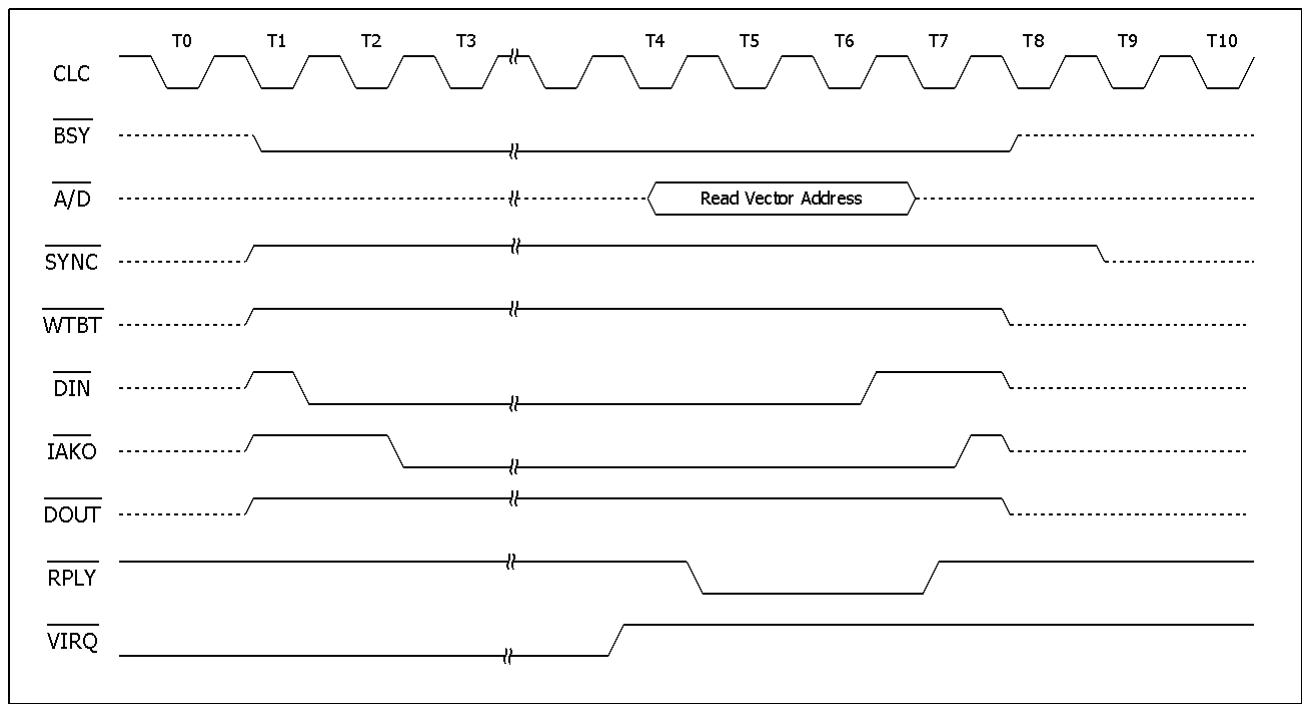
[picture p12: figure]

Допустим, что в такте Т0 на магистрали МПИ нет ведущего устройства (однако обычно это не так, процессор сохранял PSW и PC согласно алгоритму входа в процедуру обработки прерывания), обмен не выполняется, полагаем это состояние исходным. По срезу Т1 микропроцессор осуществляет захват магистрали, при этом разрешается управление выходами nWTBT, nDIN, nDOUT, nIAKO. Сигнал nBSY принимает активный низкий уровень, сигнала nSYNC неактивен и остается таким на протяжении всей транзакции. На выходе nWTBT установлен высокий уровень, что означает выполнение операции чтения, выходы nAD находятся в высокоимпедансном состоянии, шина готова к приему данных от устройства. По фронту Т1 на выходе nDIN формируется активный низкий уровень. Через такт, по фронту Т2 на выходе nIAKO формируется низкий уровень и далее микропроцессор переходит в состояние ожидания данных (адреса вектора прерывания) и сигнала подтверждения nRPLY от ведомого устройства. При этом запускается специальный таймер монитора шины, который осуществляет счет с частотой CLC/8. Если сигнал подтверждения nRPLY не будет получен в течение 56...64 тактов CLC, то цикл обмена прерывается и возникает программное исключение по вектору 1600128. Разброс в величине таймаута связан с тем, что фаза предделителя частоты CLC/8 при запуске таймера не обнуляется - предделитель считает непрерывно.

На диаграмме в такте Т4 внешнее устройство выставляет данные, которые подлежат считыванию микропроцессором, и затем, по прошествии некоторого интервала формирует активный низкий уровень сигнала подтверждения nRPLY. В общем же случае, согласно ГОСТ 26765.51-86, актуальные данные должны быть выставлены ведомым устройством не позднее чем 200 нс после среза активации сигнала nRPLY. На диаграмме момент выставления nRPLY, который определяется внешним устройством, намерено показан после фронта T4. Микропроцессор фиксирует сигнал на своем входе nRPLY по фронту тактового сигнала, при обнаружении активного низкого nRPLY два фронта тактового сигнала подряд (на приведенной диаграмме это T5 и T6, два цикла нужны так как данные от ведомого устройства могут запаздывать на интервал до 200 нс относительно активации nRPLY), цикл обмена полагается законченным, по фронту T6 фиксируются читаемые данные и передаются внутренним схемам процессора, снимается активный сигнал nDIN и останавливается таймер монитора шины, затем в такте T7 деактивируется сигнал nIAKO и происходит переход в ожидание снятия активного сигнала nRPLY. При этом по срезу тактового сигнала осуществляется детектирование неактивного высокого уровня nRPLY и при обнаружении такового запрещаются выходы управляющих сигналов nDIN, nDOUT, nWTBT, nIAKO.

Ведомое устройство, которое выставило вектор на шину может снять активный запрос nVIRQ если у него больше нет других запросов на прерывание.

Ниже в справочных целях приведена диаграмма выполнения транзакции "Чтение вектора прерывания" из ГОСТ 26765.51-86 с указанием регламентируемых временных параметров.

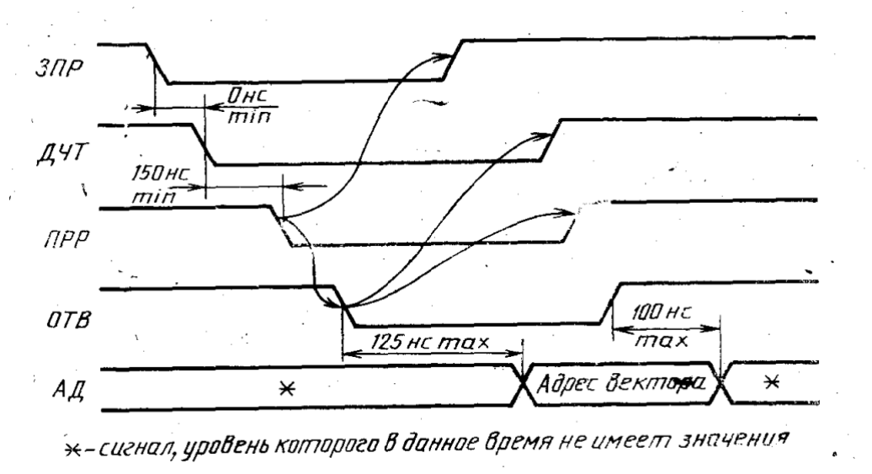
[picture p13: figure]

### 5.5 Процедура арбитража доступа к магистрали

Ниже в справочных целях приведена диаграмма выполнения транзакции "Захват магистрали" из ГОСТ 26765.51-86 с указанием регламентируемых временных параметров.

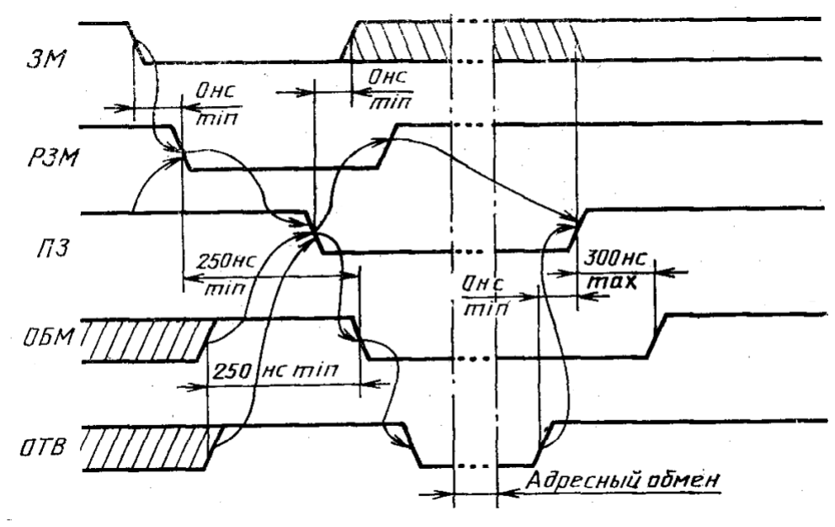
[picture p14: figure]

### 5.6 Поддержка многопроцессорной конфигурации

Процессор К1801ВМ1 поддерживает работу в многопроцессорной конфигурации, которая позволяет строить системы, содержащие до четырех процессоров К1801ВМ1, непосредственно подключенных к общей шине. Каждому процессору в такой системе присваивается аппаратный номер от 0 до 3. Аппаратный номер процессора определяется комбинацией сигналов на входах nPA1 и nPA0:

nPA1=1, nPA0=1 - процессор номер 0, высший приоритет доступа к шине
nPA1=1, nPA0=0 - процессор номер 1
nPA1=0, nPA0=1 - процессор номер 2
nPA1=0, nPA0=0 - процессор номер 3

Если процессор единственный в системе (однопроцессорный вариант), то на данные входы должен быть подан высокий уровень. Процессор номер 0 называется ведущим, процессоры 1-3 называются ведомыми. Ведущий процессор всегда должен быть на вершине цепочки nDMGI/nDMGO и имеет наивысший приоритет доступа к шине, порядок ведомых процессоров в цепочке не важен.

От аппаратного номера процессора зависит следующий функционал:

- базовый адрес блока регистров внутреннего периферийного блока, периферийный блок будет отвечать на обращения по шине только по соответствующим адресам
- адрес первого обращения к регистру начального пуска после аппаратного сброса
- биты 9 и 8 слова состояния процессора PSW
- биты 4 и 3 регистра управления режимом 1777x08
- ведущий процессор никогда не активирует nDMR
- ведомые процессоры игнорируют вход nVIRQ
- различная логика арбитража nDMGI/nDMGO для ведомых и ведущего процессоров

Адрес регистра, используемого для переключения пользовательского и пультового режимов постоянен (1777168) и не зависит от номера процессора, также постоянен адрес ячеек для сохранения/извлечения PC и PSW пультового режима (1776748). Физическое разделение этих общих ресурсов в многопроцессорной системе может быть возложено на внешние схемы.

Для программной синхронизации доступа к общим ресурсам предполагается использование инструкций, выполняющих обращение к шине при помощи транзакции чтение-модификация-запись. Процессор К1801ВМ1 выполняет такую транзакцию на шине МПИ атомарно, с монопольным захватом шины на все время выполнения транзакции. Например, процедуры захвата и освобождения синхронизирующего объекта (spinlock) могут быть основаны на инструкциях DECB или ASRB:

lock:
cmpb | spinlock, #1
bne | lock
decb | spinlock
bne | lock
rts | PC

unlock:
mov | #1, spinlock
rts | PC

lock:
asrb | spinlock
bcc | lock
rts | PC

unlock:
mov | #1, spinlock
rts | PC

### 6. Периферийный блок

Внутри микросхемы К1801 также имеется периферийный блок, который подключен к внешним выводам магистрали МПИ и может играть роль встроенного ведомого устройства магистрали. Это означает что регистры периферийного блока могут читаться и записываться по МПИ как внутренним процессорным блоком микросхемы, так и внешним по отношению к микросхеме агентом шины, например, другим процессором.

Базовый адрес периферийного блока зависит от физического номера процессора в системе (задается значениями на входах nPA0, nPA1):

Входы | Номер процессора | Диапазон адреса
nPA1=1, nPA0=1 | процессор номер 0 | 1777008-1777168
nPA1=1, nPA0=0 | процессор номер 1 | 1777208-1777368
nPA1=0, nPA0=1 | процессор номер 2 | 1777408-1777568
nPA1=0, nPA0=0 | процессор номер 3 | 1777608-1777768

При обращении к диапазону адресов базового блока процессор всегда генерирует ответный сигнал nRPLY, не требуется его формирование дополнительными внешними схемами. При обращении по адресу база внутреннего периферийного блока + 168 дополнительно генерируется активный внешний сигнал nSEL1 низкого уровня, независимо от того какой агент, внутренний или внешний обращается к данному адресу. При обращении по адресу база внутреннего периферийного блока + 148 дополнительно генерируется активный внешний сигнал nSEL2. Сигналы nSEL1 и nSEL2 фиксируются по ниспадающему фронту nSYNC и остаются неизменными на протяжении всего цикла обмена шины до нарастающего фронта nSYNC.

При обращении к периферийному блоку по смещениям 0008-0128 данные выдаются и принимаются внутренними схемами микропроцессора - регистрами управления и ВЕ-таймера. При обращении по смещениям 0148-0168 данные должны быть выданы или приняты внешними схемами. Следующая таблица раскрывает особенности обращений к внутреннему периферийному блоку микросхемы:

Операция | Агент шины | Адрес обращения | Линии nAD | nRPLY
чтение | внутренний | вне диапазона блока | вход | внешний
| | база + 0008-0128 | выход | внутри
| | база + 0148-0168 | вход | внутри
| внешний | вне диапазона блока | вход | внешний
| | база + 0008-0128 | выход | внутри
| | база + 0148-0168 | вход | внутри
запись | внутренний | вне диапазона блока | вход | внешний
| | база + 0008-0128 | выход | внутри
| | база + 0148-0168 | вход | внутри
| внешний | вне диапазона блока | вход | внешний
| | база + 0008-0128 | вход | внутри
| | база + 0148-0168 | вход | внутри

Под внутренним агентом понимается собственный процессорный блок микросхемы, под внешним -внешний процессор или другое устройство, осуществившее захват шины и являющееся в момент обращения ведущим. Таблица также показывает состояние линий nAD, при состоянии выход на шину транслируется содержимое соответствующего регистра, из которого осуществляется чтение, или данные, записываемые в регистр внутренним процессорным блоком. Последний столбец отображает формирование сигнала nRPLY, при обращении к периферийному блоку сигнал nRPLY формируется всегда.

Регистры периферийного блока можно условно разделить на три группы:

- регистры управления и состояния - смещения 0008-0048
- регистры ВЕ-таймера - смещения 0068-0128
- внешние регистры nSEL2 и nSEL1 - смещения 0148-0168

Данные регистры описаны в следующих разделах.

### 6.1 Регистр управления режимом

Name: CPU_MODE

Offset: 1777008 + <номер процессора> * 208 | Reset Value: 1777408 (зависит от номера)
15 | 14 | 13 | 12 | 11 | 10 | 9 | 8 | 7 | 6 | 5 | 4 | 3 | 2 | 1 | 0
Readonly (Write ignored) | | | | | | | | | | | | | R & W
1 | 1 | 1 | 1 | 1 | 1 | 1 | 1 | 1 | 1 | 1 | PA1 | PA0 | WT | ST | HLT

Регистр режима, начальное значение 1777408 (зависит от аппаратного номера процессора)

Биты 0,1,2 регистра режима используются для синхронизации пуска подчиненных процессоров главным процессором в многопроцессорной системе, т. к. блок регистров каждого процессора доступен на шине любому другому процессору вне зависимости от состояния процессора-владельца

HLT - останов конвейера обработки микрокоманд. Процессор останавливается полностью, выход из этого состояния возможен только при сбросе этого бита, выполняемого внешним агентом на шине МПИ путем прямой записи в регистр или по аппаратному сбросу микропроцессора. При выполнении микрокода это бит также может устанавливаться записью 0 в 25 разряд специального управляющего вектора, но рабочая версия микропрограммы эту возможность никогда не использует.

ST - остановить конвейер микроинструкций после загрузки регистра инструкций. Если этот бит имеет единичное значение, то при загрузке слова кода очередной команды в регистр инструкций, происходит установка бита HLT и конвейер останавливается, таким образом, возможно пошаговое исполнение программы под управлением внешнего агента по шине МПИ.

WT - при установке этого бита происходит переход в режим ожидания прерывания, бит автоматически устанавливается инструкцией WAIT. При наступлении разрешенного прерывания этот бит сбрасывается и происходит переход из режима ожидания прерывания в рабочий режим. Физически этот бит совпадает с флагом WCPU в блоке прерываний. Может управляться микропрограммой через запись в специальный управляющий вектор.

PA1, PA0 - аппаратный номер процессора в многопроцессорной системе, для ведущего процессора в данном поле считывается значение 0, для ведомых - 1,2 или 3.

### 6.2 Регистр вектора прерывания рестарта

Name: CPU_IVEC

Offset: 1777028 + <номер процессора> * 208 | Reset Value: N/A
15 | 14 | 13 | 12 | 11 | 10 | 9 | 8 | 7 | 6 | 5 | 4 | 3 | 2 | 1 | 0

Write only (Read as 1777778)

Unknown

Регистр адреса прерывания, начальное значение 1777778, только для записи

Данный регистр представляет собой рудиментарный остаток от К1801ВЕ1. Предполагалось что при записи в данный регистр записываемое значение будет сохраняться и при этом активироваться запрос на прерывание. Пока данный запрос на прерывание не будет обработан, регистр вектора рестарта делается более недоступным по шине - при обращении к нему не генерируется nRPLY, и также запись нового значения не осуществляется. Таким образом внешний агент может узнать, что процессор-владелец регистра еще не обработал прерывание. Обработка возникшего запроса предполагалась по вектору, значение которого было записано в данный регистр рестарта. Однако ни К1801ВМ1А, ни К1801ВМ1Г не реализует полный функционал запроса на прерывание от регистра вектора рестарта - данный запрос просто не подключен к блоку обработки прерываний. При записи произвольных данных в регистр он "пропадает" из адресного пространства, так как внутренний запрос на прерывание установлен и блокирует генерацию nRPLY. Но, как выяснилось, процессоры К1801ВМ1 ошибочно сбрасывают этот запрос на прерывание при обработке инструкции EMT, таким образом регистр вектора рестарта становится снова доступен на шине.

### 6.3 Регистр флагов ошибок

Name: CPU_ERROR

Offset: 1777048 + <номер процессора> * 208 | Reset Value: 1774408
15 | 14 | 13 | 12 | 11 | 10 | 9 | 8 | 7 | 6 | 5 | 4 | 3 | 2 | 1 | 0
Readonly (Write ignored) | | | | | | | | Read & Write
1 | 1 | 1 | 1 | 1 | 1 | 1 | 1 | ER7 | OAT | 1 | QTO | ER3 | ER2 | UOP | DBL

Регистр ошибки, начальное значение после сброса 1774408 - все используемые флаги ошибок очищены. Единичное значение флага означает что имела место соответствующая ошибочная ситуация.

DBL - double error - двойная ошибка (повторная установка битов UOP, QTO, OAT, ER7)

UOP - unknown opcode - недопустимая команда, взывает сброс микропрограммного автомата

ER2 – резервный бит, не вызывает исключений, никогда не устанавливается микрокодом

ER3 – резервный бит, не вызывает исключений

QTO - qbus timeout - тайм-аут обращения к внешнему устройству

OAT - odd address trap - словное обращение по нечетному адресу, поскольку детектор обращения по нечетному адресу в К1801ВМ1 заблокирован на аппаратном уровне, то данный бит никогда не устанавливается.

ER7 - резервный бит, не вызывает исключений, но может вызвать двойную ошибку

Все биты ошибок безусловно сбрасываются при загрузке нового кода команды во внутренний регистр инструкций, таким образом, регистр ошибок отображает ошибочные ситуации, возникшие при выполнении текущей команды. Поэтому значение некоторых битов ошибок не может быть прочитано программным способом самим процессором - инструкция успешного чтения данных из самого регистра выполняется без ошибок DBL, UOP, QTO, OAT, эти биты будут сброшены. Но регистр ошибок может быть прочитан внешним агентом на шине МПИ (например, другим процессором) и полученная информация может быть использована в отладочных и диагностических целях.

Биты ER2, ER3, ER7 могут устанавливаться микропрограммой через запись в специальный управляющий вектор, но на практике рабочей версией микропрограммы эта возможность не используется, вероятно эти флаги могли использоваться при отладке микропрограммы.

### 6.4 Регистры встроенного таймера К1801ВМ1

Встроенный таймер К1801ВМ1 является унаследован от однокристального микроконтроллера К1801ВЕ1. Таймер является недокументированным, и некоторый процент микросхем К1801ВМ1А/Б/В имеют неработоспособный блок встроенного таймера. Микросхема К1801ВМ1Г имеет гарантировано работоспособный блок таймера, а также дополнительно поддерживает прерывание от этого блока.

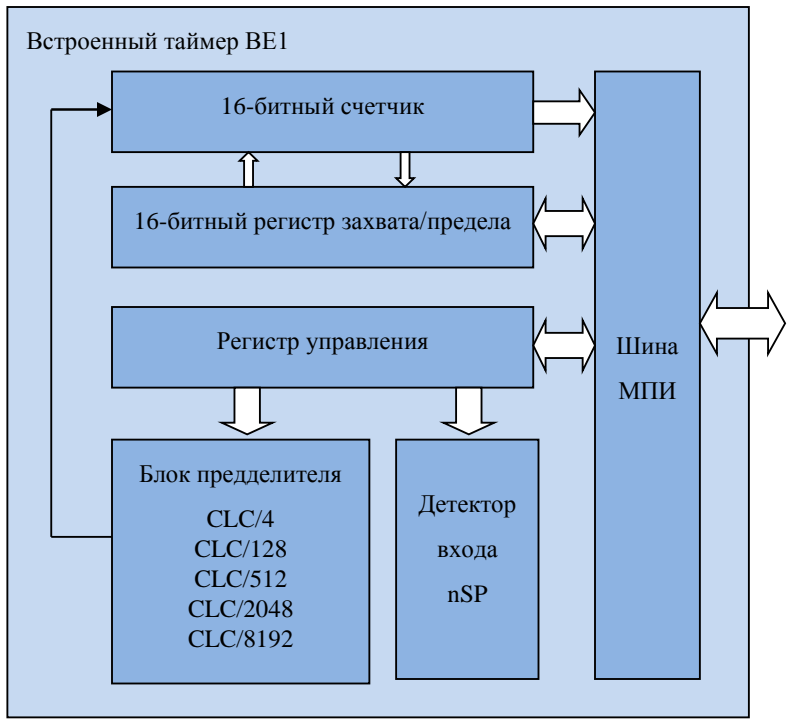
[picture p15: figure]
Встроенный таймер ВЕ1; 16-битный регистр захвата/предела; Детектор; входа; nSP; Шина; МПИ; 16-битный счетчик; Регистр управления; Блок предделителя; CLC/4 CLC/128 CLC/512 CLC/2048 CLC/8192

Таймер имеет в своем составе следующие блоки:
- 16-битный декрементируемый счетчик
- 16-битный регистр значения перезагрузки и/или захвата текущего значения счетчика
- регистр управления таймером
- регистр управления
- предделитель входной процессорной частоты CLC на 4
- дополнительный делитель частоты CLC на 12810 (формируется делением CLC/4 на 32)
- детектор ниспадающего фронта на входе nSP
Тактирование счетчика таймера может осуществляться одной из следующего набора частот:
- внешняя тактовая частота, поступающая на внешний вход микросхемы nSP
- частота с предделителя CLC/128
- частота с предделителя CLC/128 дополнительно деленная на 4
- частота с предделителя CLC/128 дополнительно деленная на 16
- частота с предделителя CLC/128 дополнительно деленная на 64
Также в процессоре К1801ВМ1Г таймер может генерировать прерывания по вектору 2708, в процессоре К1801ВМ1А данная функция отключена, прерывания от таймера не генерируются

Все внутренние управляющие схемы таймера тактируются частотой CLC/4. Предделитель и делители CLC недоступны из программы, работают постоянно и не сбрасываются при обращении к регистрам таймера или при сбросе всего процессора по входу nDCLO.

Для внешней частоты nSP счетный такт формируется по ниспадающему фронта сигнала, синхронизированного с частотой CLC/4, поэтому значение входной частоты не может быть больше, чем CLC/8, а длительность любого полупериода должна превышать длительность периода CLC/4.

Таймер может быть настроен на следующие режимы:
- декрементный счет с остановом по достижению счетчика нулевого значения
- декрементный счет с перезагрузкой счетчика значением из регистра перезагрузки при достижении счетчика нулевого значения с последующим продолжением счета
- декрементный счет с захватом текущего значения счетчика в регистре перезагрузки при обнаружении ниспадающего фронта на входе nSP. В этом режиме счетчик не останавливается при достижении нуля, а переходит на значение 1777778. Обратное копирование из регистра перезагрузки в регистр счетчика при достижении счетчиком нуля в данном режиме не выполняется.

### 6.5 Регистр значения перезагрузки и захвата

Name: TVE_LIMIT

Offset: 1777068 + <номер процессора> * 208 | Reset Value: N/A
15 | 14 | 13 | 12 | 11 | 10 | 9 | 8 | 7 | 6 | 5 | 4 | 3 | 2 | 1 | 0

Read & Write

Limit

Limit – 16-битное начальное значение счета

Может быть настроен режим, при котором в данный регистр копируется содержимое регистра счета по ниспадающему фронту на внешнем входе nSP.

Вне зависимости от режима работы, при записи со стороны процессора в регистр управления таймера TVE_CSR содержимое регистра TVE_LIMIT копируется в регистр счетчика TVE_COUNT.

Начальное значение регистра после включения питания не определено, зависит от того в какое псевдослучайное состояние установятся триггеры регистра. Сброс по входам nINIT и nDCLO никак не изменяет состояние регистра TVE_LIMIT.

### 6.6 Регистр счетчика таймера

Name: TVE_COUNT

Offset: 1777108 + <номер процессора> * 208 | Reset Value: N/A
15 | 14 | 13 | 12 | 11 | 10 | 9 | 8 | 7 | 6 | 5 | 4 | 3 | 2 | 1 | 0

Readonly (Write Ignored)

Count

Count – 16-битное текущее значение счетчика таймера

Декрементируется с частотой nSP, или CLC/128 опционально деленной на 4, 16 или 64. Если настроен режим перезагрузки счетчика значением из регистра TVE_LIMIT, то перезагрузка осуществляется в течение 4 тактов CLC (не CLC/128) после перехода счетчика из значения 1 в значение 0, таким образом, счетчик последовательно принимает следующие значения: N, N-1, N-2, ...., 3, 2, 1, (кратковременный 0), N, N-1... Фаза предделителя и делителей, а также фаза детектора ниспадающего фронта nSP при этом сохраняется неизменной и равномерность периода счета не нарушается. Для простоты программной модели можно считать, что значение 0 пропускается, хотя при некотором стечении обстоятельств и может быть прочитано из регистра.

Вне зависимости от режима работы таймера, при каждой записи в регистр управления TVE_CSR происходит переписывание значения регистра TVE_LIMIT в регистр TVE_COUNT.

При условии, что не установлен бит CAP в регистре TVE_CSR происходит загрузка счетчика значением из регистра TVE_LIMIT при достижении счетчиком нулевого значения. Тут имеется особенность - загрузка происходит только в том случае, если счетчик перед этим был ненулевым (имел единичное значение и был декрементирован), если же в TVE_LIMIT записано нулевое значение, то оно загружается один раз, далее условие ненулевого значения счетчика в предыдущем такте не выполняется и новой загрузки не происходит. В следующем такте счета счетчик принимает значение 1777778 и продолжает дальнейший счет.

Начальное значение регистра после включения питания не определено, зависит от того в какое псевдослучайное состояние установятся триггеры регистра. Сброс по входам nINIT и nDCLO никак не изменяет состояние регистра TVE_COUNT.

### 6.7 Регистр управления таймера

Name: TVE_CSR

Offset: 1777128 + <номер процессора> * 208 | Reset Value: 1774008
15 | 14 | 13 | 12 | 11 | 10 | 9 | 8 | 7 | 6 | 5 | 4 | 3 | 2 | 1 | 0
Readonly | | | | | | | | Read & Write
1 | 1 | 1 | 1 | 1 | 1 | 1 | 1 | FL | D4 | D16 | RUN | OS | MON | CAP | SP

FL – Аппаратно устанавливается схемой таймера в единицу в случае наступления события таймера. Событием таймера может быть момент перехода счетчика через нуль или захват текущего значения счетчика по ниспадающему фронту на входе nSP. Для установки бита FL должен быть разрешен мониторинг события таймера - бит MON должен быть установлен программой в единичное значение. На самом деле, при наступлении события таймера (переход счетчика через нуль или захват значения счетчика) генерируется запрос на прерывание, при запуске обработки прерывания данный запрос сбрасывается. Бит FL устанавливается только в том случае если возник новый запрос на прерывание, а старый еще не был обработан. Поскольку функция обслуживания прерывания от таймера в К1801ВМ1А заблокирована, то бит FL будет реально установлен только после второго срабатывания таймера. После включения питания или сброса nDCLО при самом первом событии таймера данный бит не устанавливается. При втором и последующих событиях этот бит работает правильно, поскольку внутренний флаг запроса на прерывание уже установлен. Для процессора К1801ВМ1Г возможна обработка прерываний от таймера, и бит FL будет выполнять роль флага переполнения - будет устанавливаться при возникновении события если прерывание от предыдущего события еще не обработано

D4 – разрешить делитель на 4, делители 1/4 и 1/16 включаются последовательно

D16 – разрешить делитель на 16, делители 1/4 и 1/16 включаются последовательно

RUN – запись единицы разрешает работу счетчика, значение из TVE_LIMIT копируется в TVE_COUNT и далее значение счетчика будет уменьшатся на единицу с заданной частотой. Запись нуля останавливает счетчик (при этом значение из TVE_LIMIT также копируется в TVE_COUNT, как и при любой записи в регистр управления). Если установлен бит OS, то при достижении нулевого значения счетчика данный бит будет сброшен аппаратной схемой таймера. Бит RUN сбрасывается только событием перехода через нуль при сброшенном бите CAP. По событию захвата при ниспадающем фронте на входе nSP и установленном бите CAP счетчик не останавливается и всегда продолжает счет.

OS – использовать однократный режим, при достижении счетчиком нуля, бит RUN будет сброшен, таймер перезагружен и остановлен. Для использования этого режима также необходимо сбросить бит CAP, т.е. если оба бита OS и CAP установлены, то таймер не остановится при переходе счетчика через нуль, а будет продолжать отсчет, так как установленный бит выбирает генерацию события таймера по ниспадающему фронту на входе nSP.

MON – разрешить мониторинг события таймера - "переход счетчика через нуль" или "захват значения счетчика", устанавливать бит FL при возникновении события таймера. Также для К1801ВМ1Г данный бит разрешает запрос прерывания от таймера.

CAP - режим захвата, по ниспадающему фронту на входе nSP осуществить копирование регистра счетчика TVE_COUNT в регистр предела TVE_LIMIT, при этом генерируется событие таймера. Бит RUN также должен быть установлен, иначе событие не генерируется. При нулевом значении бита CAP таймер генерирует событие при переходе счетчика через значение нуль и осуществляет загрузку регистра счетчика из регистра предела.

SP - выбор режим тактирования счетчика таймера по ниспадающему фронту на входе nSP, делители на 4 и на 16 в данном случае никак не влияют на результирующую частоту тактирования таймера.

Таблица частоты тактирования счетчика таймера

D4 | D16 | SP | Частота
x | x | 1 | вход nSP (CLC/810 максимальная)
0 | 0 | 0 | CLC/12810
0 | 1 | 0 | CLC/204810
1 | 0 | 0 | CLC/51210
1 | 1 | 0 | CLC/819210

Режимы работы таймера

RUN | OS | CAP | Режим
0 | x | x | Остановлен
1 | 0 | 0 | Непрерывный счет с перезагрузкой счетчика
1 | 1 | 0 | Однократный счет с предзагрузкой счетчика
1 | x | 1 | Непрерывный счет без перезагрузки счетчика, захват значения счетчика по входу nSP

### 7. Процессорный блок

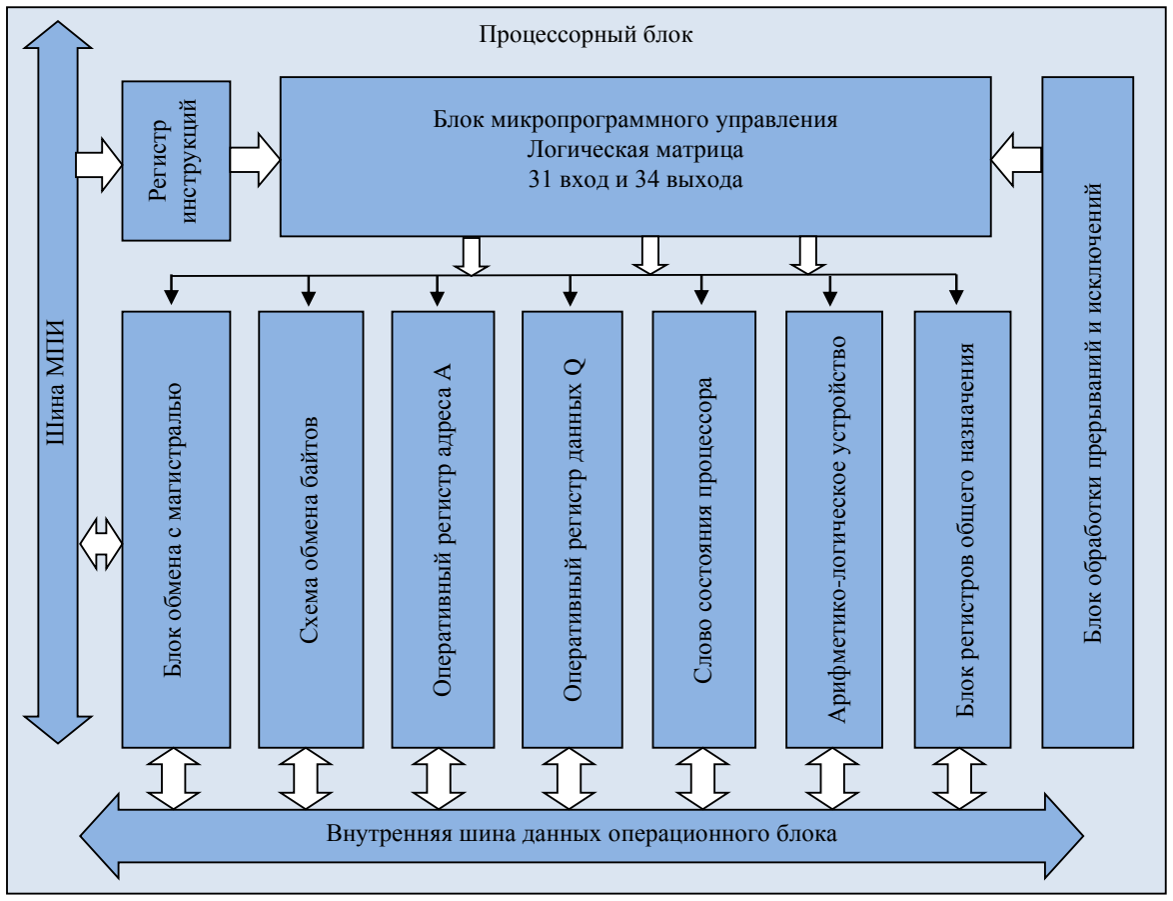
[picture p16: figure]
Процессорный блок; Блок микропрограммного управления Логическая матрица 31 вход и 34 выхода; Регистр; инструкций Блок обмена с магистралью; Схема обмена байтов; Оперативный регистр данных; Блок регистров общего назначения; Слово состояния процессора; Оперативный регистр адреса; Блок обработки прерываний и исключений; Арифметико-логическое устройство; Шина МПИ; Внутренняя шина данных операционного блока

В составе процессорного блока можно выделить следующие основные компоненты:

- блок микропрограммного управления, осуществляет декодирование инструкций и формирование необходимых последовательностей сигналов для их выполнения в других обрабатывающих блоках процессора, использует отдельный внутренний регистр инструкций, в котором хранится код исполняемой инструкции
- блок обработки прерываний и исключений, получает на входы все имеющиеся сигналы прерываний и исключений, сигналы их маскирования или запрета, производит их упорядочивание по приоритету и передает информацию о текущем наиболее приоритетном событии блоку микропрограммного управления
- операционный блок, выполняет собственно обработку и хранение данных, содержит в своем составе отдельную внутреннюю шину данных, блок взаимодействия с шиной МПИ, схему обмена байтов, оперативный регистр данных Q, оперативный регистр адреса транзакции МПИ A, слово состояния процессора PSW, арифметико-логическое устройство и блок регистров общего назначения

### 7.1 Блок микропрограммного управления

Ниже приведена диаграмма блока микропрограммного управления и источники входных сигналов данного блока. Выходы блока управляют работой практически всех остальных блоков процессора.

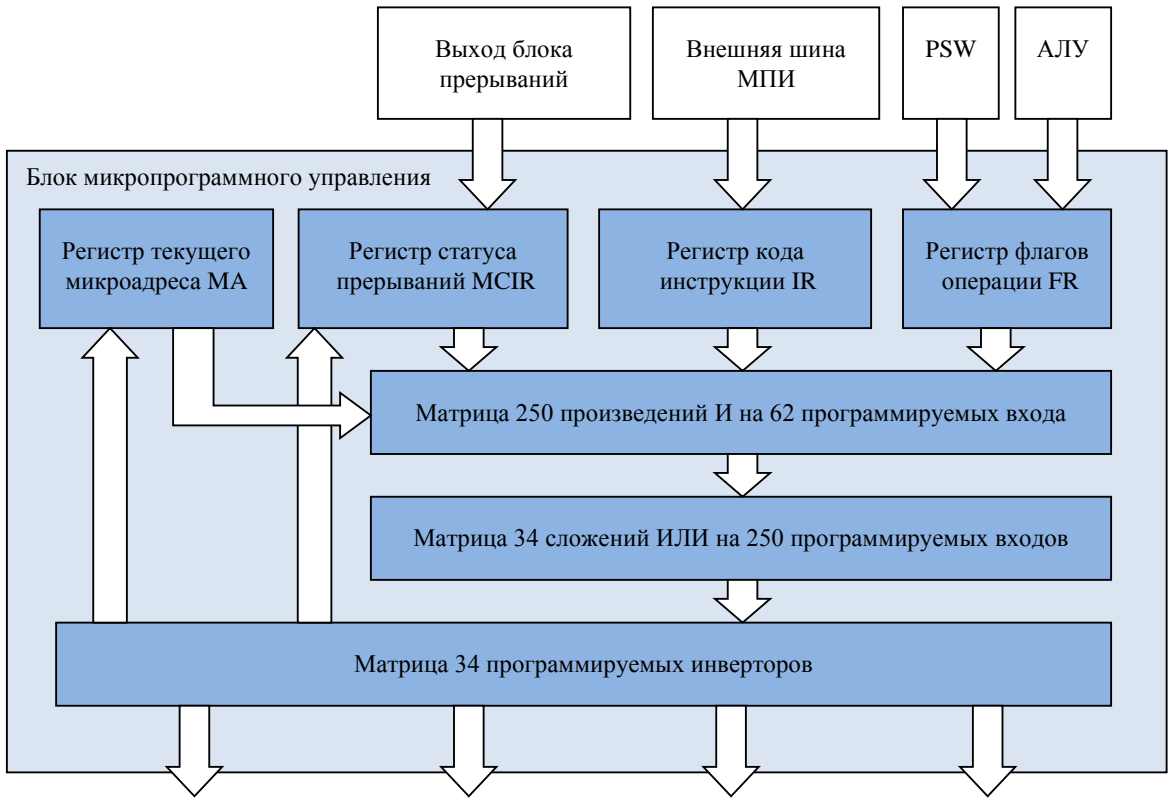
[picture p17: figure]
Блок микропрограммного управления; Регистр статуса прерываний MCIR; Регистр текущего микроадреса MA; Внешняя шина МПИ; Регистр флагов операции FR; Выход блока прерываний; Регистр кода инструкции IR; PSW; АЛУ; Матрица 34 программируемых инверторов

В блоке микропрограммного управления можно выделить следующие компоненты:

- регистр микроадреса MA, этот регистр содержит 7-битное значение адреса текущей микроинструкции. При аппаратном сбросе процессора регистр микроадреса безусловно принимает значение 00, обеспечивая начальный пуск. При возникновении ситуации микросброса (внутренний сброс микропрограммного автомата, возникает по ряду причин -недопустимый код инструкции, тайм-аут ввода-вывода и прочее) регистр принимает значение 01, обеспечивая прекращение выполнения текущей машинной инструкции и принудительный безусловный переход к последовательности микроинструкций обработки исключений. Во всех остальных случая регистр микроадреса принимает значение адреса следующей микроинструкции в последовательности, формируемое на части выходов логической матрицы
- регистр статуса прерывания MCIR, этот регистр содержит 3-битное значение, обычно формируемое блоком обработки прерываний и исключений. Также значение может формироваться с выходов логической матрицы, это используется при обработке инструкций программных исключений типа HALT, IOT и тому подобных
- регистр инструкций IR, 16-битный регистр, содержащий слово текущей машинной инструкции, записывается исключительно результатом транзакций чтения внешней шины. На некоторых этапах работы микропрограммного автомата значение этого регистра

Матрица 250 произведений И на 62 программируемых входа

Матрица 34 сложений ИЛИ на 250 программируемых входов игнорируется, например, при начальном пуске или обработке неопределенного кода инструкции

- регистр флагов FR, внутренний 5-битный регистр, старший разряд всегда принимает значение четвертого разряда слова состояния процессора (флаг T), остальные разряды могут также загружаться из младших битов PSW, либо получать значения арифметических флагов напрямую от АЛУ. Это сделано для возможной микропрограммной реализации различных сложных инструкций типа MUL, без модификации программно-видимых арифметических флагов
- универсальная программируемая логическая матрица на 31 вход и 34 выхода. Матрица реализует 34 универсальных однобитовых функции от 31 входных аргументов. Время прохождения сигналов через матрицу составляет два такта частоты CLC. В моменты времени, когда работа матрицы не требуется (например, идет ожидание завершения операции чтения на шине МПИ) с транзисторов матрицы снимается питание, что приводит к снижению потребления структурами n-МОП. Матрица содержит три ступени – логические умножения, логические сложения и выходные инверторы. Ступень логических умножений содержит 250 функций логических произведений от 31 входного аргумента и 31 инверсии входных аргументов. Под программированием матрицы понимается что в функции произведений могут быть включены входные аргументы и их инверсии в произвольном порядке, или не подключены вовсе. Подключение аргументов производится масочным способом при производстве микросхемы и не может быть изменено в процессе дальнейшей эксплуатации. Вторая ступень содержит 34 функции логического сложения каждая от 250 аргументов, аргументами являются выходы функций логического умножения первой стадии. Функции логического сложения второй стадии также являются программируемыми – масочным способом задаются подключаемые аргументы. Выходы функций второй ступени поступают на программируемые 34 инвертора, инверсия которых также задается масочным способом при изготовлении микросхемы. Такая структура матрицы позволяет реализовать независимые варианты 34 комбинационных функций.
Микропроцессоры | К1801ВМ1А | и | К1801ВМ1Г | имеют | различные | варианты
программирования матрицы, соответственно в них реализованы различные варианты поведения микропрограммного автомата

Функционирование блока микропрограммного управления основано на переборе микроадресов. Как таковых микроинструкций нет, есть набор микроадресов, загружаемых в регистр MA. Значение этого регистра и ряд других аргументов подается на вход матрицы, матрица формирует среди прочих значений поле следующего микроадреса NA – это значение, которое будет загружено в конце цикла в регистр MA.

Цикл работы микропрограммного автомата занимает минимум 2 такта входной частоты CLC, но может быть удлинен на произвольное количество тактов по ряду причин:

- ожидание готовности результата АЛУ
- ожидание завершения чтения данных на шине МПИ, когда данные нужны в качестве аргумента для операции АЛУ, данные будут занесены в регистр Q и использованы в операции
- ожидания завершения чтения кода инструкции на шине МПИ и записи его в регистр инструкций IR
- ожидание завершения опроса блока прерываний
- ожидание освобождения регистра адреса A для инициирования новой транзакции на шине МПИ в конвейере

В каждом цикле работы микропрограммного автомата АЛУ принимает два входных аргумента с шин X и Y и выполняет заданную арифметическую или логическую операцию, результат которой выдается на шину X и опционально может быть записан или в регистре общего назначения, или в регистр слова состояния PSW, или в регистры адреса A и данных Q. В регистры адреса или данных опционально может осуществляться запись аргумента с шины X до выполнения операции АЛУ, например так запускается чтение слова кода очередной инструкции по значению счетчика PC, при этом в данном цикле АЛУ выполняет операцию сложения PC (блок РОН выдает на шину X) + 2 (генератор констант выдает на шину Y), но в регистр адреса будет записано значение еще до модификации, это позволяет уменьшить количество циклов микропрограммного автомата, нужных для обработки процессорных инструкций. Также в каждом цикле может быть опционально запущен опрос блока прерываний, который завершается записью регистров MCIR и VSEL. Эти регистры могут быть записаны также непосредственно в ходе обработки некоторых инструкций (EMT, TRAP, и так далее) и использованы для последующего вызова обработки исключений.

Характерные последовательности перебора микроадресов при обработке прерываний и
исключений, а также исполнении процессорных | инструкций приведены | в разделе описания
микропрограммы.

Назначение выходов блока микропрограммного управления

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
~NA5
~NA4
~NA3
NA2
NA1
NA0

Адрес следующей микроинструкции, значение, формируемое данными выходами, будет загружено в регистр текущего микроадреса MA после выполнения текущей микроинструкции. При аппаратном сбросе процессора или внутреннем сбросе микропрограммного автомата данное поле игнорируется

01
02
03
TPLM | Определяет операцию с регистром инструкций IR, возможна произвольная комбинация
| | операций: • запуск чтения кода следующей инструкции на шине МПИ • ожидание завершения чтения и записи прочитанного значения в регистр IR • запуск опроса блока прерываний и получения результата в MCIR
| MCIR | Wait | Read | Примечание
000 | нет | нет | нет | нет операции
001 | нет | да | нет | ожидание завершения чтения кода следующей инструкции в IR, при этом текущая инструкция RTT
010 | нет | нет | нет | нет операции
011 | да | да | да | запуск чтения кода следующей инструкции по шине МПИ (если не было запущено ранее) с ожиданием завершения, одновременный запуск проверки состояния блока обработки прерываний
100 | нет | нет | да | ранняя предвыборка кода следующей инструкции, чтение на шине МПИ запускается, но его завершение не ожидается в данном микроцикле
101 | да | нет | нет | только проверка наличия прерываний, используется инструкцией WAIT
110 | нет | нет | нет | нет операции
111 | да | да | нет | ожидание завершения чтения кода следующей инструкции в IR, при этом текущая инструкция не RTT
06 07 08 | QBUS | Флаг байтовой операции на шине МПИ Флаг операции записи на шине МПИ Флаг операции чтения на шине МПИ
00x | нет операции
010 | запись слова
011 | запись байта
100 | чтение слова
101 | чтение байта (читается слово)
110 | чтение-модификация-запись слова
111 | чтение-модификация-запись байта

4 21 22 | PLOP | Управление записью арифметических флагов PSW из результирующих флагов АЛУ
10 | Не ожидать данные чтения на шине МПИ
11 13 | PLX | Данные флаги являются многофункциональными, определяют тип операнда на шине Y, разрешают запись специального управляющего вектора, определяют тип операции АЛУ
12 | UOP | Неопределенная операция, при возникновении этого активного флага микропрограммный автомат переходит на адрес 01, все операции записи блокируются, устанавливается флаг запроса на исключение Undefined Opcode. Таким образом прекращается исполнение текущей последовательности микроинструкций и происходит переход на начальный анализ исключений. Также установка данного флага вызывает безусловный запрос на заполнение регистра MCIR блоком прерываний, в итоге процессор начнет обрабатывать исключение по вектору 0000108 (если нет более приоритетных исключений). Флаг генерируется на всех недопустимых адресах, а также как результат декодирования кода инструкции в регистре IR.
| | Флаг также блокирует на протяжении текущего микроцикла любые записи в регистры, слово состояния, и запуск транзакций на шине МПИ — это позволяет избежать разрушения состояния микропроцессора при неопределенной операции

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
| | Код операции АЛУ или выбор типа операнда на шине Y: 11, 13 и 14 разряды определяют тип операнда на шине Y - регистр, константа или вектор,
000x, 0011 | X + Y
0010 | X & ~Y
010x, 0111 | Y - X
0110 | X ^ Y
1000 | Y
10x1 | X
1010 | X | Y
110x, 1111 | X - Y
1110 | X & Y

а также разрешают запись специального управляющего вектора

14 | 13 | 11 | Трансляция на шину Y
0 | 0 | 0 | R0-R13, PSW, Q (индекс в разрядах 28-25)
0 | 0 | 1 | константа ([28:25] != 00102) или вектор ([28:25] == 00102)
0 | 1 | 0 | константа ([28:25] != 00102) или вектор ([28:25] == 00102)
0 | 1 | 1 | константа ([28:25] != 00102) или вектор ([28:25] == 00102)
1 | 0 | 0 | R0-R13, PSW, Q (индекс в разрядах 28-25)
1 | 0 | 1 | константа ([28:25] != 00102) или вектор ([28:25] == 00102)
1 | 1 | 0 | R12 (предположительно не используется)
1 | 1 | 1 | R12 | константа/вектор (предположительно не используется)
18 | Признак словной операции: 0 - операция с байтом, 1 - операция со словом
20 | Фиксация - записать результат и флаги операции АЛУ в регистры РОН/PSW
23 | Не ожидать освобождения регистра A или завершения записи на шине МПИ

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
| | Данное поле имеет несколько значений: Индекс регистра, определяет что будет выставлено на входную шину Y АЛУ блоком регистров. Если биты данного поля инвертировать и взять в обратном порядке, то получится индекс регистра, совпадающий (для регистров 0-7) с регистровым индексом в полях процессорных инструкций.
0000 | R0 | 0100 | R4 | 1000 | R8 | 1100 | R12
0001 | R1 | 0101 | R5 | 1001 | R9 | 1101 | R13
0010 | R2 | 0110 | R6 | 1010 | R10 | 1110 | PSW
0011 | R3 | 0111 | R7 | 1011 | R11 | 1111 | Q

Также поле отвечает за выбор константы, выдаваемой на шину Y как аргумент АЛУ (см. описание поля OP13-OP17):

0000 | IR[3:0] - SEx/CLx | 1000 | IR[7:0] <<1 со знаком
0001 | 0003408 | 1001 | 1000008
0010 | VSEL table | 1010 | 1776768
0011 | 0000028 | 1011 | 0000208
0100 | IR[5:0] <<1 - SOB | 1100 | флаг переноса C
0101 | 1777168 | 1101 | 1774008
0110 | 1777778 | 1110 | 0000108
0111 | 0000018 | 1111 | 0000008

Также поле определяет режим сдвигателя на выходе АЛУ для одноадресных операций сдвига, если разряды 13 и 14 оба единичные, то разряды 27-25 определяют режим сдвига АЛУ и работу схемы обмена байт на входе X АЛУ:

000 | влево, в младший бит вдвигается 0, ASL
001 | влево, в младший бит вдвигается 0, ASL
010 | влево, в младший бит вдвигается С, ROL
011 | нет сдвига, перестановка байт на входе АЛУ с шины X
100 | вправо, старший бит копируется, ASR
101 | вправо, в старший бит вдвигается перенос из старшего разряда АЛУ в текущей операции
110 | вправо, в старший бит вдвигается C, ROR
111 | нет сдвига

30 31 32 33 | ~X3 ~X2 ~X1 ~X0 | Индекс аргумента X (биты инвертированы и порядок переставлен для совпадения с индексов регистра в поле процессорной инструкции), определяет что будет выставлено на общую шину X АЛУ блоком регистров:
0000 | R0 | 0100 | R4 | 1000 | R8 | 1100 | R12
0001 | R1 | 0101 | R5 | 1001 | R9 | 1101 | R13
0010 | R2 | 0110 | R6 | 1010 | R10 | 1110 | PSW
0011 | R3 | 0111 | и | 1011 | R11 | 1111 | Q

Если разряды 11 и 13 оба единичные, то происходит запись выходов логической матрицы в специальный управляющий вектор. Специальный управляющий вектор — это динамический набор стробов, управляющий работой различных блоков процессора. Назначение разрядов логической матрицы, соответствующих стробам:

7 | 0 - установить флаг WCPU, при опросе блока прерываний микропрограммный автомат будет остановлен и процессор перейдет в режим ожидания внешних прерываний, используется при выполнении инструкции WAIT
27 | 0 - сбросить флаг WCPU и запустить на шине МПИ транзакцию подтверждения прерывания, процессор выходит из режима ожидания внешнего прерывания
10 | 0 - активировать внешний сигнал nINIT. Значение внешнего выходного сигнала nINIT хранится в однобитовом регистре, который устанавливается в активное значение при записи управляющего вектора с нулевым 10-ым разрядом и устанавливается в неактивное при записи вектора с нулевым 23-им разрядом, используется при исполнении инструкции RESET
23 | 0 - деактивировать внешний сигнал nINIT. Значение внешнего выходного сигнала nINIT хранится в однобитовом регистре, который устанавливается в активное значение при записи управляющего вектора с нулевым 10-ым разрядом и устанавливается в неактивное при записи вектора с нулевым 23-им разрядом, используется при исполнении инструкции RESET
25 | 0 - установить флаг HLT в регистре управления режимом (1777008 + <номер процессора> * 208), практически эта возможность рабочей версией микропрограммы не используется, процессор остановится
26 | 0 – установить флаг ER2 в регистре ошибок (1777048 + <номер процессора> * 208), практически эта возможность рабочей версией микропрограммы не используется
28 | 0 – установить флаг ER3 в регистре ошибок (1777048 + <номер процессора> * 208), практически эта возможность рабочей версией микропрограммы не используется
30 | 0 – установить флаг ER7 в регистре ошибок (1777048 + <номер процессора> * 208), практически эта возможность рабочей версией микропрограммы не используется
14 16 17 | ~MCIR2 MCIR1 ~MCIR0 | Значение для непосредственной записи регистра статуса прерываний MCIR (см. описание блока прерываний)
18 20 21 22 | VSEL3 ~VSEL2 ~VSEL1 ~VSEL0 | Значение для непосредственной записи регистра выбора константы вектора прерываний (см. описание блока прерываний)

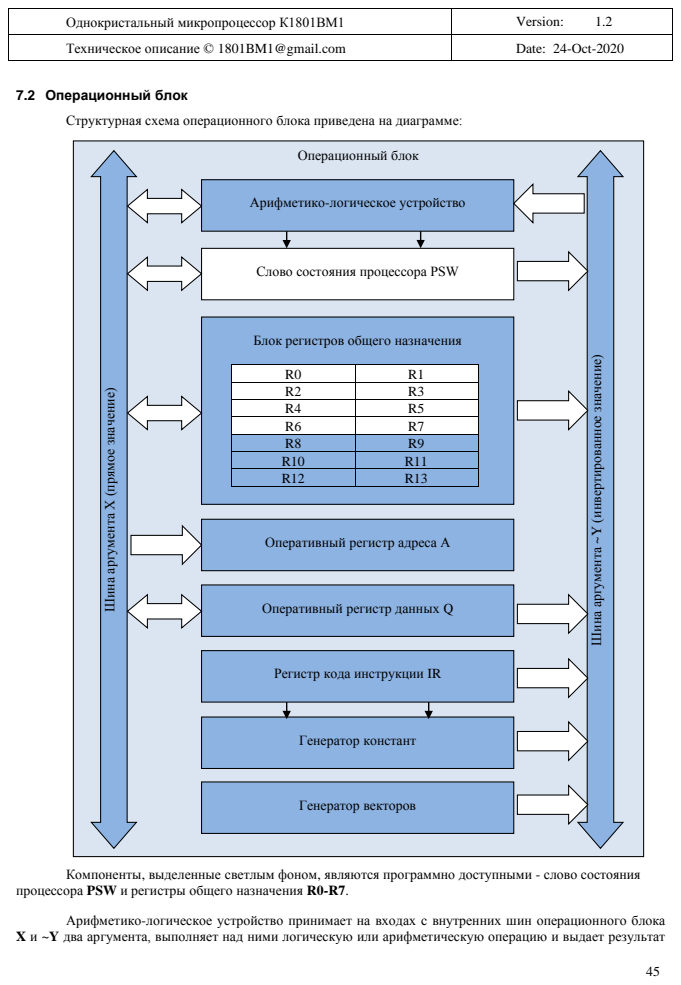
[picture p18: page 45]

Структурная схема операционного блока приведена на диаграмме:

Слово состояния процессора PSW

Блок регистров общего назначения

R0 | R1
R2 | R3
R4 | R5
R6 | R7
R8 | R9
R10 | R11
R12 | R13

Шина аргумента X (прямое значение)

Регистр кода инструкции IR

Компоненты, выделенные светлым фоном, являются программно доступными - слово состояния

процессора PSW и регистры общего назначения R0-R7.

Арифметико-логическое устройство принимает на входах с внутренних шин операционного блока

X и ~Y два аргумента, выполняет над ними логическую или арифметическую операцию и выдает результат

обратно на шину X (получение аргумента с шины X и выдача на нее результата разнесены по тактам, внутри АЛУ имеется регистр для фиксации аргумента X). Также по результатам операции вырабатываются флаги, которые могут быть опционально переписаны в слово состояния процессора PSW. Флаг переноса C может быть записан отдельно от флагов N, Z, V, которые всегда записываются единой группой. В процессоре К1801ВМ1 все арифметические операции, включая авто-инкремент счетчика команд PC, исполняются исключительно единственным основным АЛУ процессорного блока. На входе X АЛУ имеется схема обмена байт, которая опционально может переставить два байта входного аргумента местами.

Слово | состояния | процессора | PSW | содержит | арифметические | и | управляющие | флаги.
Арифметические флаги устанавливаются согласно результатам выполнения операции АЛУ, управляющие флаги могут быть только непосредственно записаны как результат прямой записи слова в PSW с шины X. При записи слова состояния с шины X запись в старший байт может быть замаскирована, предохраняя старший байт от изменения. Например, инструкция MTPS не изменяет старший байт PSW. При аппаратном сбросе процессора слово состояния обнуляется, но процедура начального старта, реализованная в микрокоде, записывает в PSW значение 0003408.

Описание флагов слова состояния процессора PSW приведено в таблице:

Бит | Имя | Описание
0 | C | Флаг переноса, устанавливается, если был перенос из старшего разряда (15-го при словных операциях и 7-го при байтовых). Операция вычитания реализовывается как сложение с инвертированным вторым операндом плюс один, поэтому при вычитании флаг переноса устанавливается если не было займа в старший разряд (не аппаратной инверсии флага переноса при вычитании). При выполнении сдвигов действуют правила описанные в соответствующих операциях
1 | V | Флаг арифметического переполнения, при сложении вычисляется как исключающее ИЛИ переносов из старшего и предстаршего разрядов. Обычно сигнализирует о потере знака результата, используется в знаковой арифметике
2 | Z | Флаг равенства результата нулю, устанавливается, если все биты результата ([15:0] при словных операциях и [7:0] при байтовых)
3 | N | Флаг знака результата, равен старшему разряду (15-му для словных операций и 7-му для байтовых)
4 | T | Флаг ловушки пошаговой отладки, исключение зависит от режима работы процессора -например, сам по себе установленный бит Т в режиме ожидания прерывания по команде WAIT не вызывает исключения. При выполнении инструкции WAIT незамаскированные прерывания IRQ1, TVE, IRQ2, IRQ3, VIRQ имеют приоритет над исключением отладки. В остальных случаях установленный бит T вызывает программное исключение по вектору 0000148. Инструкция MTPS не изменяет данный бит.
5,6 | - | Резервные биты, могут быть записаны и прочитаны, но не оказывают никакого влияния
7 | I | Единичное значение бита I маскирует следующие прерывания: - прерывание от ВЕ-таймера (только К1801ВМ1Г) - nIRQ2 - nIRQ3 - векторное прерывание nVIRQ
8 | PA0 | Младший бит номера процессора в системе, инверсное значение входа nPA0. Данный бит может быть только прочитан, не изменяется при записи
9 | PA1 | Старший бит номера процессора в системе, инверсное значение входа nPA1. Данный бит может быть только прочитан, не изменяется при записи

10 | PSW10 | Модифицирует обработку исключения зависания шины, если данный бит ненулевой, то исключение зависания будет обрабатываться в пультовом режиме по вектору 1600028 Единичное значение бита PSW10 также маскирует следующие прерывания:
- по пропаданию питания (срез на входе nACLO)
- пультовое прерывание nIRQ1
- прерывание от ВЕ-таймера (только К1801ВМ1Г)
- nIRQ2
- nIRQ3
- векторное прерывание nVIRQ
| | Бит всегда сбрасывается при входе в процедуру обработки прерывания или исключения пользовательского режима, значение бита, читаемое из вектора, игнорируется. Поскольку данный бит маскирует асинхронные прерывания пользовательского режима, то его сброс может произойти только по синхронным пользовательским исключениям (ошибки или инструкции вызова исключений). Бит также всегда сбрасывается при выполнении инструкций RTT и RTI, значение, загружаемое из стека, игнорируется. Фактически данный бит может быть установлен только при входе в обработчик прерывания или исключения пультового режима (хорошо подходит инструкция HALT), а также при возврате из него инструкциями STEP и START. Инструкция MTPS не изменяет данный бит.
11 | PSW11 | Модифицирует обработку исключения зависания шины, если данный бит ненулевой, то исключение зависания будет обрабатываться в пультовом режиме по вектору 1600028, иначе обработка по вектору 0000048 без перехода в пультовой режим Единичное значение бита PSW11 также запрещает пультовое прерывание nIRQ1. Бит всегда сбрасывается при входе в процедуру обработки прерывания или исключения пользовательского режима, значение бита, читаемое из вектора, игнорируется. Бит также всегда сбрасывается при выполнении инструкций RTT и RTI, значение, загружаемое из стека, игнорируется. Фактически данный бит может быть установлен только при входе в обработчик прерывания или исключения пультового режима (хорошо подходит инструкция HALT), а также при возврате из него инструкциями STEP и START. Инструкция MTPS не изменяет данный бит
12-15 | - | Резервные биты, могут быть записаны и прочитаны, но не оказывают никакого влияния. Обнуляются при входе в обработчик прерывания или исключения пользовательского режима – значения читаемые из вектора прерывания или исключения игнорируются. Инструкция MTPS не изменяет данные биты

Блок регистров общего назначения содержит 14 шестнадцатиразрядных регистров. При выполнении операций возможна отдельная запись только младшего байта (8 младших бит), так и запись всего шестнадцатиразрядного слова целиком, включая старший байт. Запись только младшего байта в регистры используется при байтовых операциях (за исключением MOVB, когда в старший байт регистра записывается знаковое расширение младшего байта). Блок регистров общего назначения является двух портовым ОЗУ и может обеспечить одновременную выдачу двух разных регистров на шины X и Y.

Регистры R8-R13 программно недоступны и используются микропрограммным автоматом для собственных нужд (хранение адресов операндов, временных переменных и так далее). Регистр R7 выполняет функцию программного счетчика PC и используется для адресации потока выполняемых процессорных инструкций. Регистр R6 выполняет функцию указателя стека SP, и используется в процедурах исключений и прерываний.

Оперативный регистр адреса A предназначен исключительно для записи по шине X адреса запрашиваемой транзакции МПИ. Регистр A может быть записан в различных фазах цикла микропрограммного автомата – как до выполнения операции АЛУ, так и после. Например, при запуске извлечения кода очередной исполняемой процессорной инструкции по адресу в счетчике команд PC, в регистр адреса A записывается значение PC в начале цикла, до выполнения операции автоинкремента PC+2. После записи значения адреса регистр переходит в занятое состояние и освобождается после выполнения фазы трансляции адреса в транзакции на шине МПИ. Далее автомат транзакций МПИ продолжает обработку транзакции, а регистр адреса готов к записи нового значения для следующей транзакции. Таким образом, процессор К1801ВМ1 способен конвейеризировать до двух транзакций МПИ. При записи в регистр адреса также фиксируется тип транзакции, для сохранения типа также предусмотрен буфер хранения до двух транзакций МПИ. При записи регистра адреса процессор выполняет следующие действия:

- Ожидает завершения предыдущих транзакций МПИ, если таковые есть
- Выставляет запрос на захват шины и ожидает ее предоставления
- Начинает фазу трансляции адреса (активный выход nSYNC)
- После завершения фазы трансляции адреса переходит к фазе чтения данных для транзакций чтения и чтения-модификации-записи (активный выход nDIN)
- Если транзакция подразумевает запись, то ожидается запись регистра Q, таковая может быть выполнена еще до записи регистра А или после, в транзакция модификации ожидается запись в регистр Q результатов модификации данных со стороны АЛУ
- Ожидание завершения транзакций не производится, ожидание данных происходит на уровне микропрограммного автомата

Оперативный регистр данных Q служит для сохранения данных прочитанных в результате транзакций чтения по шине МПИ, а также для сохранения данных, записываемых по шине X со стороны АЛУ, предназначенных для последующей записи по шине МПИ во внешние устройства или память.

Регистр кода инструкции IR предназначен для хранения кода текущей процессорной инструкции, обрабатываемой в данный момент микропрограммным автоматом. Также имеется теневой регистр для хранения кода следующей инструкции, полученной в результате предварительной выборки (чтение кода инструкции, запущенное заранее, еще в ходе обработки текущей инструкции).

Генераторы констант и векторов выдают на шину Y одно из постоянных значений из фиксированного набора. В набор входят значения векторов исключений, некоторые константы для вычислений - -1, 0, 1, 2, а также фиксированные адреса регистров и указателя стека пультового режима.

Во многих документах и обсуждениях, касающихся К1801ВМ1, встречается упоминание так называемого “пультового режима”. На самом деле внутри процессора нет никаких специальных схем и состояний для специального пультового режима. Вместо этого предусмотрен условный бит управления режимом, вынесенный во внешние схемы - бит 3 регистра 1777168 (этот адрес НЕ зависит от физического номера процессора, одинаков для всех процессоров в многопроцессорной системе). При входе в некоторые исключения микропрограмма вызывает обращение к регистру 1777168 и установку бита, такие исключения называются исключениями пультового режима. Специальные инструкции START и STEP производят возврат из таких исключений (являются аналогами инструкций RTI и RTT), при этом также производится обращение к регистру 1777168 и сброс бита 3.

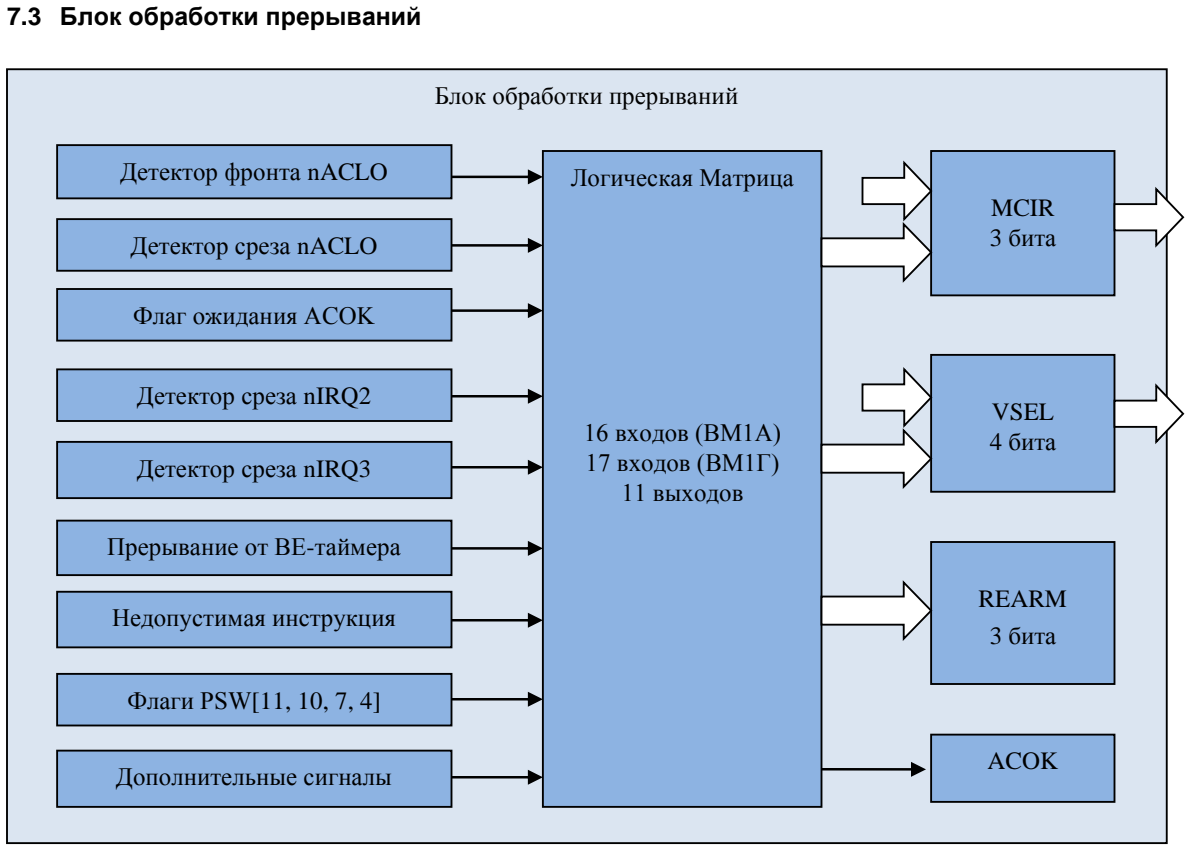
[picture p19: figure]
7.3 Блок обработки прерываний; Блок обработки прерываний; Детектор фронта nACLO; Прерывание от ВЕ-таймера; Логическая Матрица; 16 входов (ВМ1А) 17 входов (ВМ1Г) 11 выходов; Детектор среза nACLO; Флаг ожидания ACOK; Детектор среза nIRQ2; Детектор среза nIRQ3; Недопустимая инструкция; Флаги PSW[11, 10, 7, 4]; Дополнительные сигналы; VSEL 4 бита; MCIR 3 бита; REARM; 3 бита; ACOK

Блок обработки прерываний принимает и детектирует запросы на прерывания и исключения от различных источников, упорядочивает их по приоритету, выполняет маскирование и передает информацию о имеющемся наиболее приоритетном незамаскированном активном запросе для блока микропрограммного управления.

Запросы на прерывание или исключение поступают на детектор. Детектор производит непрерывную проверку линии запроса и при обнаружении события фиксирует соответствующий флаг. Например, детектор среза nACLO будет выставлять активный флаг при обнаружении перехода входа nACLO в низкий уровень. Флаг останется выставленным до события аппаратного сброса процессора или до тех пор, пока информация об этом запросе не будет передана и обработана блоком микропрограммного управления.

Обнаруженные и зафиксированные запросы поступают на логическую матрицу, которая также обрабатывает функции маскирования и упорядочивания запросов по приоритетам. Матрица имеет 19 входов в К1801ВМ1А и 20 входов в К1801ВМ1Г (в последнем дополнительный вход является запросом прерывания от ВЕ-таймера, в остальном матрицы одинаковы) и 11 выходов. 3 входа являются резервными и не используются.

Выходные сигналы матрицы фиксируются в трех отдельных регистрах и одном флаге:

- MCIR - 3-битовый регистр флагов наличия прерываний, его выход напрямую подается на матрицу блока микропрограммного управления. Этот регистр может быть записан как с выходов матрицы блока прерываний, так и данными со стороны микропрограммного блока. Запись этого регистра со стороны блока микропрограммного управления используется при отработке программных исключений, вызываемых инструкциями типа HALT, EMT и т. д.

- VSEL - 4-битовый регистр индекса вектора прерывания. Подается на вход таблицы генератора констант, может быть записан как с выходов матрицы блока прерываний, так и данными со стороны микропрограммного блока.
- REARM - 3-битовый регистр, определяет индекс детектора события, флаг которого должен быть сброшен, используется исключительно внутри блока прерываний для сигнализации детектору события что флаг обработан и надо реактивироваться для обнаружения следующего события.
- ACOK - флаг нормального старта. Этот флаг обнуляется при аппаратном сбросе микропроцессора, и блок прерываний переходит в ожидание события фронта на nACLO. При этом блоку микропрограммного управления сообщается специальный код, и тот находится в пустом начальном цикле, ожидая начального старта.

Блок микропрограммного управления в первом такте декодирования инструкции выполняет транзакцию опроса блока прерываний. При этой транзакции опроса блок прерываний записывает информацию о имеющихся запросах в регистр MCIR, также в регистр VSEL записывается индекс требуемого вектора прерывания. Если на выход для обработки передан запрос с детектора события, то соответствующий детектор сбрасывается. Например, детектор среза nIRQ3 обнаружил событие среза, выставил соответствующий флаг запроса, когда этот флаг будет обработан (что необязательно происходит в первом же цикле опроса, так как запрос может быть замаскирован флагами в слове состояния PSW или могут иметься более приоритетные запросы), то в регистр REARM будет записан код для сброса именно детектора nIRQ3 и детектор инициализируется и перейдет в ожидание нового события среза по этой линии.

Значения регистра MCIR и реакция блока микропрограммного управления на них

0002 | Ожидание прерывания. Блок микропрограммного управления постоянно выполняет опрос блока прерывания в цикле и никаких других операций не производится. Это состояние используется для ожидания начального пуска - флаг ACOK сброшен, блок прерывания ожидает фронта nACLO. И также при выполнении инструкции WAIT - постоянно ожидается поступление прерывания.
0012 | Нет активных незамаскированных запросов на прерывание или исключение
01x2 | Переход в "пультовый" режим (по инструкции HALT, низкому уровню на входе nIRQ1, двойной ошибке). Внутри процессора нет специального пультового режима, бит управления режимом вынесен во внешние схемы - бит 3 регистра 1777168 (адрес НЕ зависит от физического номера процессора). При входе в режим осуществляется чтение-модификация-запись внешнего регистра 1777168 с установкой маски 108. Установленный младший бит указывает что не требуется выполнять коррекцию PC (уменьшение на 2) перед сохранением в стеке
10x2 | Требуется обработка прерывания или исключения пользовательского режима, установленный младший бит указывает что не требуется выполнять коррекцию PC (уменьшение на 2) перед сохранением в стеке
11x2 | Выполнить последовательность начального старта (прочитать регистр начального старта, инициализировать PC и PSW)

Значения регистра VSEL и соответствующие индексам значения векторов

008 | 1600068 - исключение по двойной ошибке шины
018 | 0000208 - инструкция IOT (это значение индекса вектора никогда не генерируется блоком прерываний, а записывается со стороны микропрограммного блока при декодировании инструкции)

028 | 0000108 - зарезервированный код инструкции
038 | 0000148 - установленный бит T в слове состояния процессора PSW
048 | 0000048 - тайм-аут (зависания) внешней шины
058 | Адрес начального пуска, значение вектора зависит от физического номера процессора 1777168 - процессор номер 0 1777368 - процессор номер 1 1777568 - процессор номер 2 1777768 - процессор номер 3
068 | 0000308 - инструкция EMT (это значение индекса вектора никогда не генерируется блоком прерываний, а записывается в регистр MCIR со стороны микропрограммного блока при декодировании инструкции)
078 | 1600128 - тайм-аут шины при приеме вектора прерывания
108 | 0002708 - обнаружение спада на входе nIRQ3, или ВЕ-таймер (только К1801ВМ1Г)
118 | 0000248 - обнаружение спада на входе nACLO
128 | 0001008 - обнаружение спада на входе nIRQ2
138 | 1600028 - низкий уровень на входе nIRQ1 или инструкция HALT
148 | 0000348 - инструкция TRAP (это значение индекса вектора никогда не генерируется блоком прерываний, а записывается со стороны микропрограммного блока при декодировании инструкции)
158 | Получить вектор прерывания от внешнего устройства (это значение индекса вектора никогда не генерируется блоком прерываний)
168 | Получить вектор прерывания из регистра вектора прерывания рестарта 1777x28 (это значение индекса вектора никогда не генерируется блоком прерываний, так как эта возможность не реализована в микропроцессоре, вероятно рудиментарный остаток от К1801ВЕ1)
178 | 0000008 - неиспользуемый вектор

Значения регистра REARM и соответствие детекторам

0002 | Флаг | неопределенной | инструкции | UERR. | этот | флаг | устанавливается | блоком
микропрограммного управления при обнаружении ошибки декодирования кодов операций, после установки флага ошибки блок микропрограммного управления сбрасывается и переходит к моменту опроса состояния блока прерывания. Флаг неопределенной инструкции является приоритетным и немаскируемым и блок прерывания выставляет соответствующий код, вызывающий переход блока микропрограмм к процедуре обработки исключения. После передачи кода блок прерываний очищает этот флаг. Также этот индекс сбрасывает флаги таймаутов по внешней шине для данных и вектора прерываний - QBTO и IATO.
0012 | Флаг обнаружения спада на входе nIRQ3
0112 | Флаг обнаружения спада на входе nIRQ2
1002 | Флаги обнаружения фронта и спада на входе nACLO
1012 | Флаг прерывания от ВЕ-таймера, устанавливается таймером, сбрасывается при обработке прерывания, есть только в К1801ВМ1Г

Таблица входов матрицы и формируемые выходные значения

Вход | Описание | MCIR | VSEL | REA
ACOK | Флаг ожидания начального пуска, при аппаратном сбросе микропроцессора этот флаг сбрасывается и будет установлен только после возникновения события фронта на входе nACLO и обработки этого события матрицей (флаг устанавливается значением с выхода матрицы, после первичной установки будет оставаться установленным постоянно). После обработки начального пуска флаг устанавливается и в дальнейшей работе влияния на матрицу не оказывает
| ACOK=0, ACIN=0 (нет фронта nACLO) | 0002 | 118 | 1112
| ACOK=0, ACIN =1 (есть фронт nACLO) | 1112 | 58 | 1002
| ACOK=1 - нормальная работа матрицы приоритетов прерываний
ACIN | Детектор фронта на входе nACLO, этот вход работает только при ожидании начального пуска, в дальнейшем не оказывает влияния на функционирование блока обработки прерываний | - | - | -
IATO | Тайм-аут получения вектора прерывания по внешней шине, всегда устанавливается вместе с флагом QBTO, сбрасывается после передачи кода блоку микропрограмм | 0112 | 78 | 0002
DBLE | Флаг двойной ошибки. Если произошел тайм-аут шины, или исключение неопределенной инструкции, и при обработке исключения снова возник тайм-аут или неопределенная инструкция, то этот флаг устанавливается. Сброс флага происходит при загрузке кода новой инструкции в регистр инструкции. На практике может возникать только двойной тайм-аут (повторная неопределенная инструкция может возникнуть только при нарушении работы микрокода), поэтому этот флаг всегда сопровождается флагом QBTO | 0112 | 08 | 0002
QBTO | тайм-аут внешней шины МПИ. При активации стробов nDIN или nDOUT запускается специальный таймер, который тактируется от делителя CLC/8, если в ответ не поступит nRPLY, то после отсчета таймером 8 тиков устанавливается флаг QBTO. Делитель частоты /8 не сбрасываемый, поэтому фактический тайм-аут может составлять от 56 до 64 тактов процессорной частоты
| PSW10=0, PSW11=0, исключение по вектору 0000048 | 1012 | 48 | 0002
| PSW10=1, PSW11=0, исключение по вектору 1600028 | 0112 | 138 | 0002
| PSW10=x, PSW11=1, исключение по вектору 1600028 Примечание: К1801ВМ1Г формирует значение MCIR=0112 | 0102 | 138 | 0002
UERR | Недопустимая инструкция, флаг устанавливается блоком микропрограммного управления при возникновении ошибки декодирования кода инструкции, загруженной в регистр инструкций. Флаг сбрасывается блоком прерываний при передаче кода старта обработки исключения блоку микропрограмм | 1012 | 28 | 0002

Вход | Описание | MCIR | VSEL | REA
| PSW, прерывание зависит от режима работы процессора -например, сам по себе установленный бит Т в режиме ожидания прерывания по команде WAIT не вызывает исключения. Ниже рассмотрены условия при PSW11=0, PSW10=0, PSW7=0, PSW4=1. То есть прерывания IRQ1, TVE, IRQ2, IRQ3, VIRQ дополнительно не замаскированы. Если установлены биты маски, то соответствующий бит запроса следует просто считать нулевым (замаскированным) в приведенных ниже выражениях. Запрос TVE присутствует только в К1801ВМ1Г, для К1801ВМ1А его следует считать неактивным (нулевым).
| WCPU=0, активный режим, прерывание по вектору 0000148 | 1002 | 118 | 0102
| WCPU=1, режим ожидания прерывания
| IRQ1=1, TVE=x, IRQ2=x, IRQ3=x, VIRQ=x, переход в пульт | 0102 | 138 | 1112
| IRQ1=0, TVE=1, IRQ2=x, IRQ3=x, VIRQ=x, прерывание таймера | 1002 | 108 | 1012
| IRQ1=0, TVE=0, IRQ2=1, IRQ3=x, VIRQ=x, прерывание nIRQ2 | 1002 | 128 | 0112
| IRQ1=0, TVE=0, IRQ2=0, IRQ3=1, VIRQ=x, прерывание nIRQ3 | 1002 | 108 | 0012
| IRQ1=0, TVE=0, IRQ2=0, IRQ3=0, VIRQ=1, прерывание nVIRQ | 1002 | 148 | 0102
| IRQ1=0, TVE=0, IRQ2=0, IRQ3=0, VIRQ=0, ожидание | 0002 | 138 | 1112
ACLO | Обнаружен ниспадающий фронт на входе nACLO, соответствует событию раннего оповещения о пропадании питания.
| PSW10=1 - ACLO замаскирован | 0012 | 138 | 1112
| PSW10=0, PSW4=1, WCPU=0 - прерывание по биту T из активного режима, вектор 0000148 | 1002 | 38 | 0102
| PSW10=0, PSW4=0 или WCPU=1 - прерывание по вектору 0000248 если нет T бита или спящий режим (режим ожидания прерывания по команде WAIT) | 1002 | 118 | 1002
IRQ1 | Прерывание "аппаратного" останова и перехода в пультовый режим, может быть замаскировано битами PSW10 или PSW11 | 0102 | 138 | 1112
TVE | Прерывание от ВЕ-таймера, детектор события достижения нуля. Имеет общий разделяемый с IRQ3 вектор 0002708, маскируется единичными битами PSW10, PSW7 и нулевым битом MON в регистре управления таймером | 1002 | 108 | 1012
IRQ2 | Прерывание по срезу на входе nIRQ2, маскируется битами PSW10, PSW7 | 1002 | 128 | 0112
IRQ3 | Прерывание по срезу на входе nIRQ3, маскируется битами PSW10, PSW7 | 1002 | 108 | 0012
VIRQ | Векторное прерывание, запрос возникает по низкому уровню на входе nVIRQ, маскируется битами PSW10, PSW7 | 1002 | 148 | 0102
PSW4 | T-бит ловушки пошаговой отладки в слове состояния процессора

Вход | Описание | MCIR | VSEL | REA
PSW7 | Единичное значение бита PSW7 маскирует следующие прерывания: - прерывание от ВЕ-таймера (только К1801ВМ1Г) - nIRQ2 - nIRQ3 - векторное прерывание nVIRQ
PSW10 | Модифицирует обработку исключения зависания шины, если
данный | бит ненулевой, | то исключение зависания будет
обрабатываться в пультовом режиме по вектору 1600028, иначе обработка по вектору 0000048 без перехода в пульт

Единичное значение бита PSW10 также маскирует следующие прерывания:
- по пропаданию питания (срез на входе nACLO)
- пультовое прерывание nIRQ1
- прерывание от ВЕ-таймера (только К1801ВМ1Г)
- nIRQ2
- nIRQ3
- векторное прерывание nVIRQ

Также замаскированные прерывания не осуществляют выход из режима ожидания по инструкции WAIT

При выполнении инструкции WAIT блок микропрограммного управления продолжает опрос блока прерывания до появления незамаскированного события

PSW11 | Модифицирует обработку исключения зависания шины, если данный бит ненулевой, то исключение зависания будет обрабатываться в пультовом режиме по вектору 1600028, иначе обработка по вектору 0000048 без перехода в пульт Единичное значение бита PSW11 также запрещает пультовое прерывание nIRQ1.
WCPU | Признак режима ожидания внешнего прерывания, вход в этот режим осуществляется по инструкции WAIT, выход по незамаскированному внешнему прерыванию. Установленный бит Т не приводит к немедленному выходу из режима ожидания, если нет активных незамаскированных аппаратных прерываний.

Таблица прерываний и исключений, значения векторов, стека сохранения PSW и PC и зависимость от маски запрета, расположены в порядке приоритета

| Описание | Вектор | PSW/PC | Маска
1 | Начальный пуск после аппаратного сброса (читается только стартовый адрес в старшем байте регистра, PSW всегда устанавливается в 3408) | 1777168 + Ncpu*208 | - -
2 | Зависание шины при получении вектора прерывания (в цикле nIAKO) | 1600128 | 1776748 | -

| Описание | Вектор | PSW/PC | Маска
3 | Двойное зависание шины (повторное при попытке обработать первое исключение по зависанию) | 1600068 | 1776748 | -
4 | Зависание шины, обработка зависит от битов 10 и 11 в PSW: если PSW11=0, PSW10=0 если хотя бы один бит PSW10 и PSW11 ненулевой | 0000048 1600028 | SP-4 1776748 | PSW11 PSW10
5 | Недопустимый код инструкции | 0000108 | SP-4 | -
6 | T-бит, бит 4 в слове состояния процессора PSW. Если данный бит имеет единичное значение, то в обычном режиме вызывает исключение по вектору 0000148. В режиме ожидания по команде WAIT T-бит не вызывает немедленного исключения, процессор ожидает прерывание, любое незамаскированное прерывание ACLO, IRQ1, TVE, IRQ2, IRQ3, VIRQ вызывает выход из этого режима и переход по вектору, соответствующему активному прерыванию | 0000148 | SP-4 | WCPU
7 | Пропадание питания - ранее оповещение, обнаружен ниспадающий фронт на входе nACLO. | 0000248 | SP-4 | PSW10
8 | Прерывание "аппаратного останова" и перехода в пультовой режим - запрос возникает при обнаружении низкого уровня на входе nIRQ1. Если уровень не будет снят после обработки запроса, то возникнет новый запрос, так как вход чувствителен к уровню, а не к фронту или срезу. Может быть замаскировано единичными битами PSW10 или PSW11 (запрещается, если хотя бы один бит установлен) | 1600028 | 1776748 | PSW10 PSW11
9 | Прерывание от ВЕ-таймера, есть только в К1801ВМ1Г , может быть замаскировано обнулением бита MON в регистре управления таймером. Также прерывание может быть запрещено битами PSW7 и PSW10 (запрещается, если хотя бы один бит установлен) | 0002708 | SP-4 | PSW10 PSW7 MON
10 | Прерывание по ниспадающему фронту на входе nIRQ2, может быть замаскировано битами PSW7 и PSW10 (запрещается, если хотя бы один бит установлен) | 0001008 | SP-4 | PSW10 PSW7
11 | Прерывание по ниспадающему фронту на входе nIRQ3, может быть замаскировано битами PSW7 и PSW10 (запрещается, если хотя бы один бит установлен) | 0002708 | SP-4 | PSW10 PSW7
-12 | Векторное прерывание от внешних устройств - запрос возникает при обнаружении низкого уровня на входе nVIRQ. Если уровень не будет снят после обработки запроса, то возникнет новый запрос, так как вход чувствителен к уровню, а не к фронту или срезу. | внешний | SP-4 | PSW10 PSW7
13 | Инструкция HALT, программное исключение, единственное программное исключение, вызывающее переход в пультовой режим. Остальные исключения пультового режима вызываются аппаратными причинами. | 1600028 | 1776748 | -
14 | Инструкция BPT, программное исключение | 0000148 | SP-4 | -
15 | Инструкция IOT, программное исключение | 0000208 | SP-4 | -
16 | Инструкция EMT, программное исключение | 0000308 | SP-4 | -

| Описание | Вектор | PSW/PC | Маска
17 | Инструкция TRAP, программное исключение | 0000348 | SP-4 | -

Если прерывание использует вектор 1600xx8, то перед сохранением текущих PSW и PC осуществляется установка бита 3 по адресу 1777168 (этот адрес НЕ зависит от физического номера процессора PA0-PA1) - таким способом осуществляется переход в "пультовый" режим, и сохранение состояния происходит уже в памяти "пультового" режима. Внутри собственно процессора нет специального "пультового" режима и каких-то выделенных для этого структур, бит управления режимом вынесен во внешние схемы. Подобная реализация делает сложным построение многопроцессорных систем – процессоры разделяют стек пультового режима и бит управления режимом (бит 3 регистра 1777168), разделение этих ресурсов может быть возложено на внешние по отношению к процессорам схемы.

При возникновении запроса на прерывание или исключение процессор выполняет следующие операции:
- при необходимости откатывает значение PC=PC-2 (зависит от младшего бита MCIR), если текущая инструкция еще не была обработана, таким образом, сохраняемый PC будет указывать на инструкцию-причину исключения
- если необходимо осуществить переход в пультовой режим (код MCIR=01x2), то на внешней шине выполняется цикл чтение-модификация-запись с установкой бита 3 в регистре 1777168 (адрес НЕ зависит от физического номера процессора PA0-PA1)
- сохраняется текущее значение PSW по адресу -(SP) или 1776768 (с использованием внутреннего регистра R12, если осуществляется переход в пультовой режим)
- сохраняется текущее значение PC по адресу -(SP) или 1776748 (с использованием внутреннего регистра R12, если осуществляется переход в пультовой режим)
- если для сохранения использовался регистр SP, то он остается модифицированным (уменьшен на 4)
- получает и сохраняет во внутреннем служебном регистре адрес вектора прерывания
- чтение нового значения PC по адресу вектор прерывания + 0
- чтение нового значения PSW по адресу вектор прерывания + 2
- возобновление выполнения программы
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

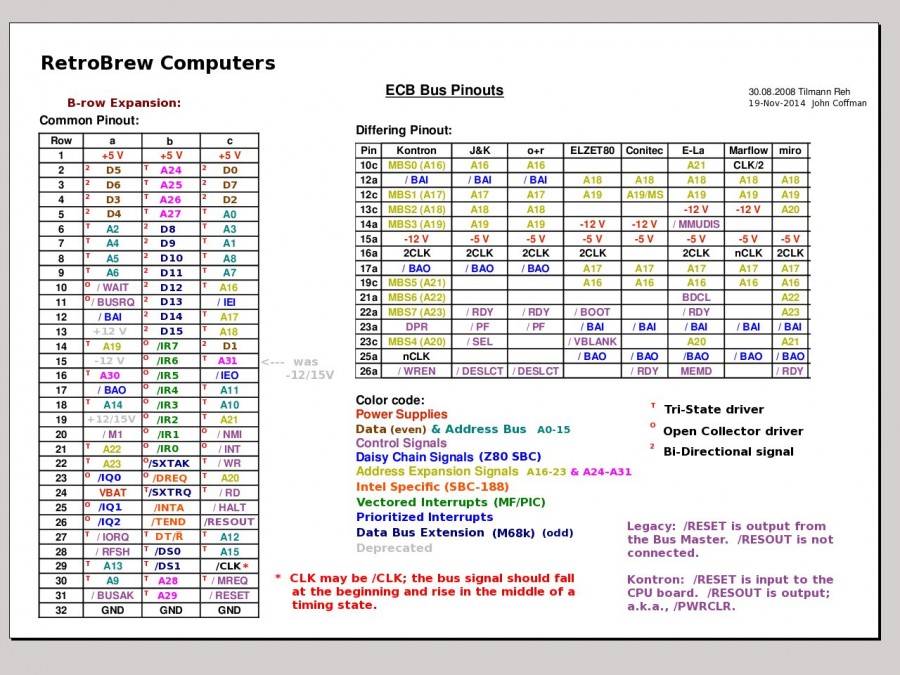
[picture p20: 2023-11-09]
docs/ecb-06.jpg

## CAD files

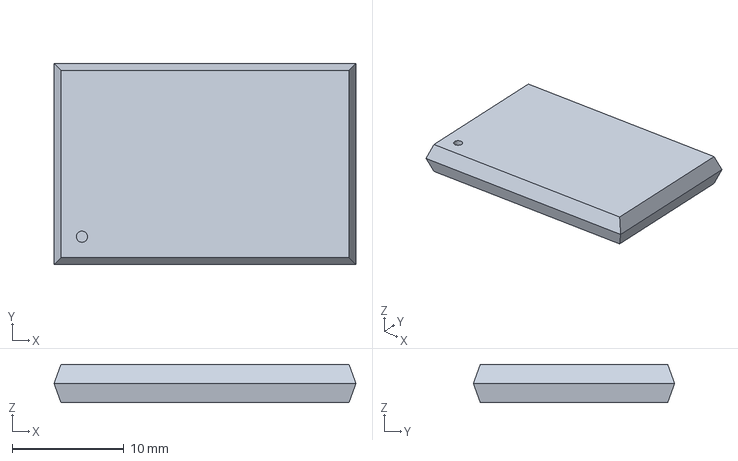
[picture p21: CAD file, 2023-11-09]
pcb/GOST_17467-89_2204.42.step
27.0 x 18.0 x 3.40 mm

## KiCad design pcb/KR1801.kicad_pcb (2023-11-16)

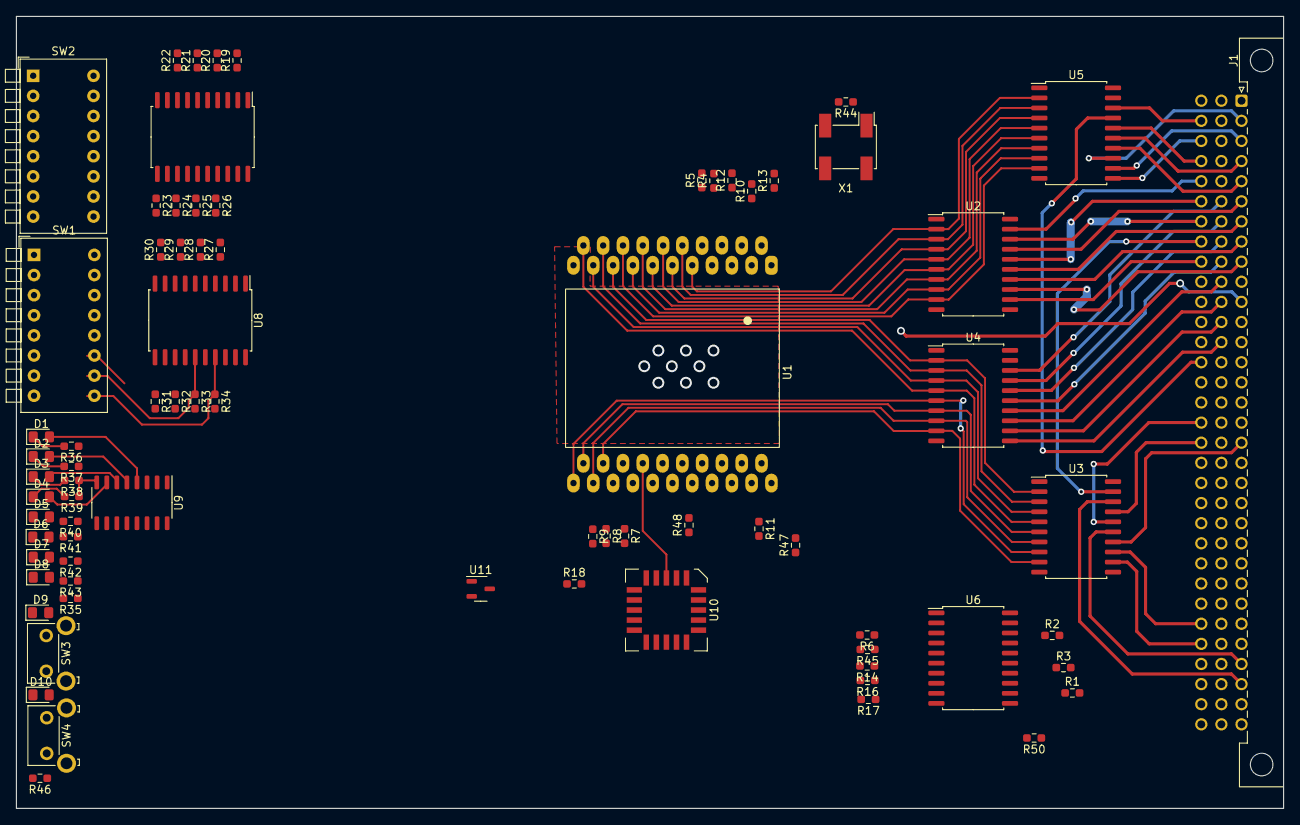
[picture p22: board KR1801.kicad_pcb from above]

Board: 2 copper layers, 160.0 x 100.0 mm, 75 parts (0 on the bottom side), 128 nets.

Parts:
D1, D2, D3, D4, D5, D6, D7, D8: LED; LED_0805_2012Metric_Pad1.15x1.40mm_HandSolder
D9: DCLO; LED_0805_2012Metric_Pad1.15x1.40mm_HandSolder
D10: NMI; LED_0805_2012Metric_Pad1.15x1.40mm_HandSolder
J1: Eurocard UNIBUS; DIN41612_C_3x32_Male_Horizontal_THT
R1, R2, R6, R8, R9, R10, R16, R17, R18, R47, R50: 0R; R_0603_1608Metric_Pad0.98x0.95mm_HandSolder
R3, R4, R5, R7, R11, R12, R13, R14, R19, R20, R21, R22, R23, R24, R25, R26, R27, R28, R29, R30, R31, R32, R33, R34, R45: R; R_0603_1608Metric_Pad0.98x0.95mm_HandSolder
R35, R36, R37, R38, R39, R40, R41, R42, R43, R46: RLED; R_0603_1608Metric_Pad0.98x0.95mm_HandSolder
R44: NPR; R_0603_1608Metric_Pad0.98x0.95mm_HandSolder
R48: WEAKR; R_0603_1608Metric_Pad0.98x0.95mm_HandSolder
SW1: Reset Vector; SW_DIP_SPSTx08_Piano_10.8x21.88mm_W7.62mm_P2.54mm
SW2: Opts; SW_DIP_SPSTx08_Piano_10.8x21.88mm_W7.62mm_P2.54mm
SW3: NMI; SW_SPST_Omron_B3F-315x_Angled
SW4: RESET; SW_SPST_Omron_B3F-315x_Angled
U1: К1801ВМ1; 2204.42
U2, U3: 74HC564; SOIC-20W_7.5x12.8mm_P1.27mm
U4, U5: 74HC640; SOIC-20W_7.5x12.8mm_P1.27mm
U6: 74AHC273; SOIC-20W_7.5x12.8mm_P1.27mm
U7, U8: 74LS240; SOIC-20W_7.5x12.8mm_P1.27mm
U9: 74LS259; SO-16_3.9x9.9mm_P1.27mm
U10: GAL16V8; PLCC-20
U11: MCP100-475D; SOT-23-3
X1: Oscillator_SMD_Fordahl_DFAS2-4Pin_7.3x5.1mm_HandSoldering

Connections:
A0: J1.c5 (A0), U2.19 (Q0)
A1: J1.c7 (A1), U2.18 (Q1)
A2: J1.a6 (A2), U2.17 (Q2)
A3: J1.c6 (A3), U2.16 (Q3)
A4: J1.a7 (A4), U2.15 (Q4)
A5: J1.a8 (A5), U2.14 (Q5)
A6: J1.a9 (A6), U2.13 (Q6)
A7: J1.c9 (A7), U2.12 (Q7)
A8: J1.c8 (A8), U3.19 (Q0)
A9: J1.a30 (A9), U3.18 (Q1)
A10: J1.c18 (A10), U3.17 (Q2)
A11: J1.c17 (A11), U3.16 (Q3)
A12: J1.c27 (A12), U3.13 (Q6)
A13: J1.a29 (A13), U3.15 (Q4)
A14: J1.a18 (A14), U3.14 (Q5)
A15: J1.c28 (A15), U3.12 (Q7)
AD0: U1.9 (~AD0), U2.2 (D0), U5.2 (A0), U7.18 (O0a)
AD1: U1.10 (~AD1), U2.3 (D1), U5.3 (A1), U7.16 (O1a)
AD2: U1.11 (~AD2), U2.4 (D2), U5.4 (A2), U7.14 (O2a)
AD3: U1.12 (~AD3), U2.5 (D3), U5.5 (A3), U7.12 (O3a)
AD4: U1.13 (~AD4), U2.6 (D4), U5.6 (A4), U7.9 (O0b)
AD5: U1.14 (~AD5), U2.7 (D5), U5.7 (A5), U7.7 (O1b)
AD6: U1.15 (~AD6), U2.8 (D6), U5.8 (A6), U7.5 (O2b)
AD7: U1.16 (~AD7), U2.9 (D7), U5.9 (A7), U7.3 (O3b)
AD8: U1.17 (~AD8), U3.2 (D0), U4.2 (A0), U8.18 (O0a)
AD9: U1.18 (~AD9), U3.3 (D1), U4.3 (A1), U8.16 (O1a)
AD10: U1.19 (~AD10), U3.4 (D2), U4.4 (A2), U8.14 (O2a)
AD11: U1.20 (~AD11), U3.5 (D3), U4.5 (A3), U8.12 (O3a)
AD12: U1.22 (~AD12), U3.8 (D6), U4.6 (A4), U8.9 (O0b), U9.13 (D)
AD13: U1.23 (~AD13), U3.6 (D4), U4.7 (A5), U8.7 (O1b), U9.1 (A0)
AD14: U1.24 (~AD14), U3.7 (D5), U4.8 (A6), U8.5 (O2b), U9.2 (A1)
AD15: U1.25 (~AD15), U3.9 (D7), U4.9 (A7), U8.3 (O3b), U9.3 (A2)
ALE: U2.11 (Load), U3.11 (Load), U10.12 (IO8)
CLC: J1.c29 (CLC), U1.1 (CLC), U6.11 (Cp), U10.1 (I1/CLK), X1.3 (OUT)
DB0: J1.c2 (D0), U5.18 (B0)
DB1: J1.c14 (D1), U5.17 (B1)
DB2: J1.c4 (D2), U5.16 (B2)
DB3: J1.a4 (D3), U5.15 (B3)
DB4: J1.a5 (D4), U5.14 (B4)
DB5: J1.a2 (D5), U5.13 (B5)
DB6: J1.a3 (D6), U5.12 (B6)
DB7: J1.c3 (D7), U5.11 (B7)
DB8: J1.b6 (D8), U4.18 (B0)
DB9: J1.b7 (D9), U4.17 (B1)
DB10: J1.b8 (D10), U4.16 (B2)
DB11: J1.b9 (D11), U4.15 (B3)
DB12: J1.b10 (D12), U4.14 (B4)
DB13: J1.b11 (D13), U4.13 (B5)
DB14: J1.b12 (D14), U4.12 (B6)
DB15: J1.b13 (D15), U4.11 (B7)
DR0: R19.1, SW2.16, U7.2 (I0a)
DR1: R20.1, SW2.15, U7.4 (I1a)
DR2: R21.1, SW2.14, U7.6 (I2a)
DR3: R22.1, SW2.13, U7.8 (I3a)
DR4: R23.1, SW2.12, U7.11 (I0b)
DR5: R24.1, SW2.11, U7.13 (I1b)
DR6: R25.1, SW2.10, U7.15 (I2b)
DR7: R26.1, SW2.9, U7.17 (I3b)
DR8: R27.1, SW1.16, U8.2 (I0a)
DR9: R28.1, SW1.15, U8.4 (I1a)
DR10: R29.1, SW1.14, U8.6 (I2a)
DR11: R30.1, SW1.13, U8.8 (I3a)
DR12: R31.1, SW1.12, U8.11 (I0b)
DR13: R32.1, SW1.11, U8.13 (I1b)
DR14: R33.1, SW1.10, U8.15 (I2b)
DR15: R34.1, SW1.9, U8.17 (I3b)
DT/~R: J1.c24 (~RD), U1.38 (~DIN), U4.1 (A->B), U5.1 (A->B), U7.19 (OEb), U8.19 (OEb), U10.2 (I2)
FAIL.LED: D9.2 (A), U10.13 (IO7)
GND: J1.a32 (GND), J1.b32 (GND), J1.c32 (GND), R35.1, R36.1, R37.1, R38.1, R39.1, R40.1, R41.1, R42.1, R43.1, R44.2, R46.1, SW1.1, SW1.2, SW1.3, SW1.4, SW1.5, SW1.6, SW1.7, SW1.8, SW2.1, SW2.2, SW2.3, SW2.4, SW2.5, SW2.6, SW2.7, SW2.8, SW3.1, SW4.1, U1.21 (GND), U2.10 (GND), U3.10 (GND), U4.10 (GND), U5.10 (GND), U6.10 (GND), U7.10 (GND), U8.10 (GND), U9.8 (GND), U10.10 (GND), U10.11 (I10/~OE), U11.3 (VSS), X1.2 (GND)
NMI.BTN: SW3.2, U10.7 (I7)
NMI.LED: D10.2 (A), U10.14 (IO6)
unnamed: D1.2 (A), U9.4 (Q0)
unnamed: D1.1 (K), R36.2
unnamed: D2.2 (A), U9.5 (Q1)
unnamed: D2.1 (K), R37.2
unnamed: D3.2 (A), U9.6 (Q2)
unnamed: D3.1 (K), R38.2
unnamed: D4.2 (A), U9.7 (Q3)
unnamed: D4.1 (K), R39.2
unnamed: D5.2 (A), U9.9 (Q4)
unnamed: D5.1 (K), R40.2
unnamed: D6.2 (A), U9.10 (Q5)
unnamed: D6.1 (K), R41.2
unnamed: D7.2 (A), U9.11 (Q6)
unnamed: D7.1 (K), R42.2
unnamed: D8.2 (A), U9.12 (Q7)
unnamed: D8.1 (K), R43.2
unnamed: D9.1 (K), R35.2
unnamed: D10.1 (K), R46.2
unnamed: J1.b28 (~DS0), R18.1
unnamed: J1.b29 (~DS1), R50.1
unnamed: R10.1, U1.3 (~DMGI)
unnamed: R8.1, U1.27 (~PA0)
unnamed: R9.1, U1.26 (~PA1)
unnamed: R16.1, U6.7 (D2)
unnamed: R17.1, U6.8 (D3)
unnamed: R1.1, U6.13 (D4)
unnamed: R2.1, U6.17 (D6)
unnamed: R47.1, U10.4 (I4)
unnamed: R6.2, U10.16 (IO4)
unnamed: R48.2, U10.15 (IO5)
unnamed: R44.1, X1.1 (OE)
VCC: J1.a1 (VCC), J1.b1 (VCC), J1.c1 (VCC), R1.2, R2.2, R3.2, R4.2, R5.2, R7.2, R8.2, R9.2, R10.2, R11.2, R12.2, R13.2, R14.2, R16.2, R17.2, R19.2, R20.2, R21.2, R22.2, R23.2, R24.2, R25.2, R26.2, R27.2, R28.2, R29.2, R30.2, R31.2, R32.2, R33.2, R34.2, R45.2, U1.42 (VCC), U2.20 (VCC), U3.20 (VCC), U4.20 (VCC), U5.20 (VCC), U6.20 (VCC), U7.20 (VCC), U8.20 (VCC), U9.16 (VCC), U10.20 (VCC), U11.2 (VDD), X1.4 (Vcc)
~ACLO: U1.30 (~ACLO), U6.2 (Q0)
~ALE: R11.1, R18.2, U1.41 (~SYNC), U10.9 (I9)
~BEN: R7.1, U1.28 (~BSY), U2.1 (OE), U3.1 (OE), U10.8 (I8)
~DCLO: J1.c31 (~RESET), SW4.2, U1.29 (~DCLO), U6.1 (~Mr), U9.15 (Clr), U10.6 (I6), U11.1 (~RST)
~DEN: U4.19 (CE), U5.19 (CE), U10.17 (I03)
~DMGO: J1.a31 (~BUSAK), U1.4 (~DMGO)
~DMR: J1.a11 (~BUSRQ), R12.1, U1.5 (~DMR)
~DOUT: J1.c22 (~WR), U1.37 (~DOUT), U10.3 (I3)
~DS1: R50.2, U10.18 (IO2)
~HALT: J1.c25 (~HALT), R14.1, U6.4 (D1)
~IAKO: J1.b25 (~INTA), U1.36 (~IAKO)
~INIT: J1.c26 (~RESOUT), R48.1, U1.34 (~INIT)
~IRQ1: U1.31 (~IRQ1), U6.5 (Q1)
~IRQ2: U1.32 (IRQ2), U6.6 (Q2)
~IRQ3: U1.33 (IRQ3), U6.9 (Q3)
~LED: U9.14 (E), U10.19 (IO1)
~NMI: J1.c20 (~NMI), R6.1, R45.1, U6.3 (D0)
~RDY: J1.a22 (~RDY), R3.1, U6.14 (D5)
~RPLY: U1.39 (~RPLY), U6.15 (Q5)
~SACK: R13.1, U1.2 (~SACK)
~SEL1: R4.1, R47.2, U1.7 (~SEL1), U8.1 (OEa)
~SEL2: R5.1, U1.8 (~SEL2)
~SP: U1.6 (~SP), U6.16 (Q6)
~VIRQ: J1.c21 (~INT), U1.35 (VIRQ), U6.12 (Q4)
~WTBT: U1.40 (~WTBT), U10.5 (I5)

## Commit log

2023-11-09 initial KiCAD commit
    [KR1801.kicad_pcb, KR1801.kicad_sch]
2023-11-09 3D models
    [650473-5.stp, GOST_17467-89_2204.42.step, KR1801.kicad_pcb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]
2023-11-10 more docs and boot
    [KR1801.kicad_sch]
2023-11-10 random placement test
    [KR1801.kicad_pcb, KR1801.kicad_sch]
2023-11-10 most of the glue logic and controls
    [KR1801.kicad_pcb, KR1801.kicad_sch, glue.kicad_sch]
2023-11-12 final logic, gal, 3D
    [650473-5.stp, KR1801.kicad_pcb, KR1801.kicad_sch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]
2023-11-14 full? schematics
    [KR1801.kicad_pcb, KR1801.kicad_sch, glue.kicad_sch]
